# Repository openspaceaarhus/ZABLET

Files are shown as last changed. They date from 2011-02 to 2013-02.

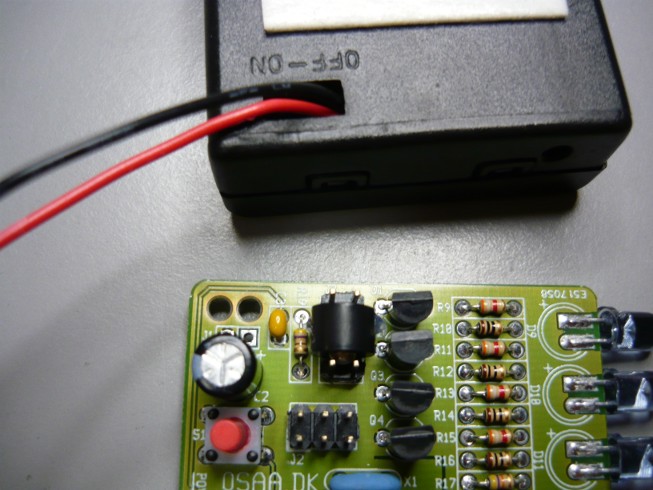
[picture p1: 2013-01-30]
doc/image/pwr-step01.jpg

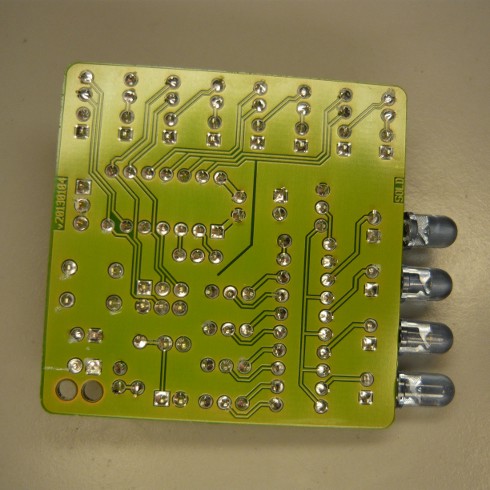
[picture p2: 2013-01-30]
doc/image/overview-pcb-sodlered-back.jpg

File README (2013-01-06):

Zab-Let
-------

Zap all TVs in your neighborhood.

This project is a derivative of the Adafruit TV-B-Gone project and includes a
POV too. The Zab-Let device was successfully used in a soldering workshop for
newbies. Version 2 fixes a few problems and extends the firmware to include the
POV part as a default.

See: http://zablet.osaa.dk
and our mailing list: http://groups.google.com/group/openspaceaarhus?hl=en

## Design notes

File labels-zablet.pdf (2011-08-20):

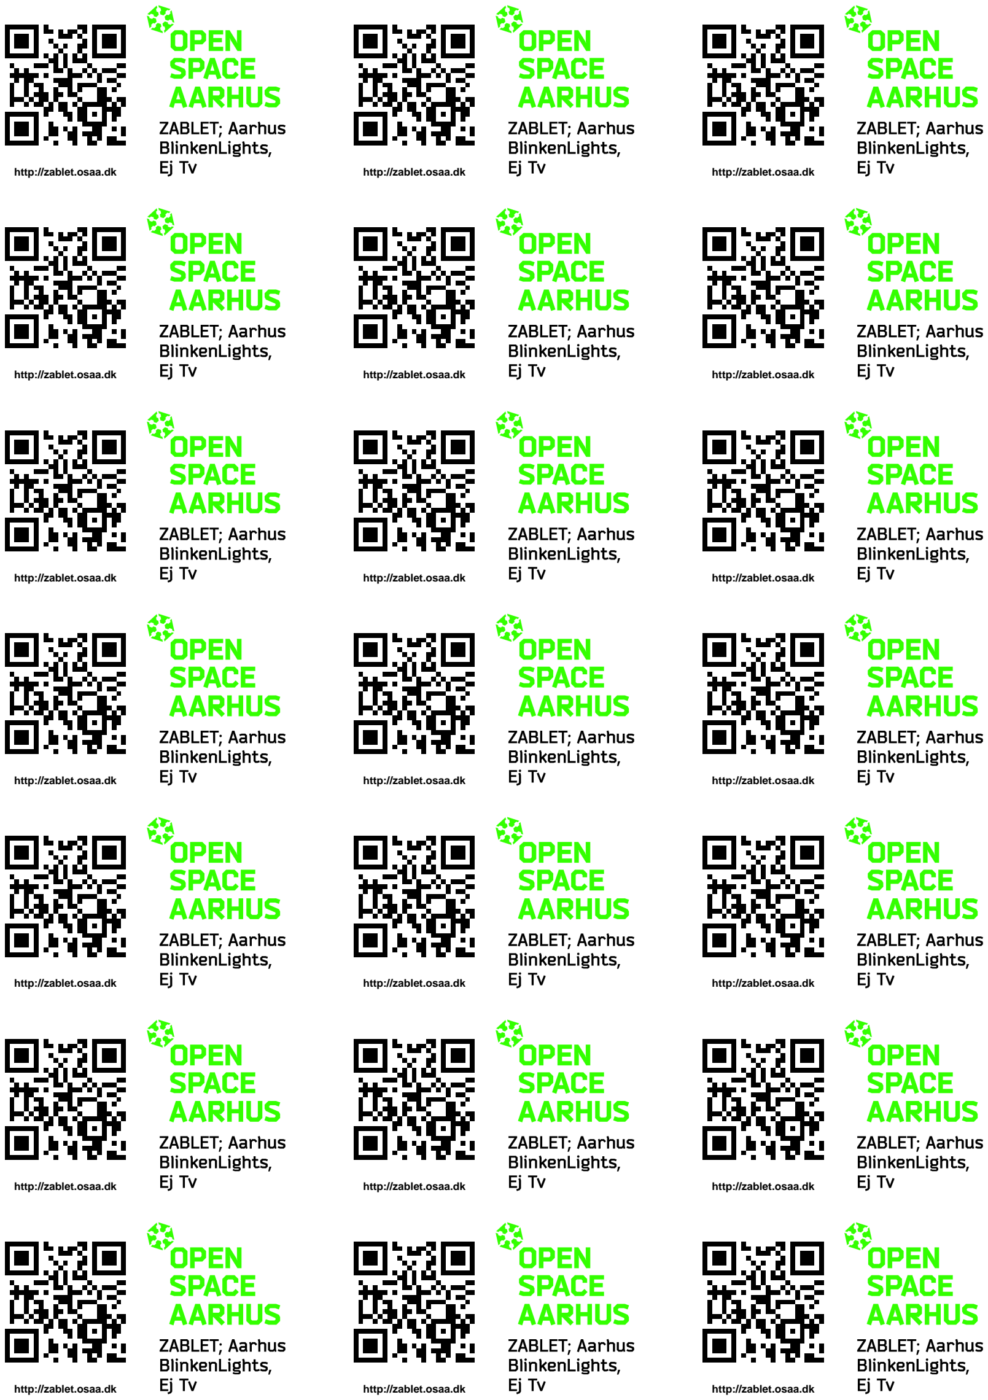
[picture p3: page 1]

http://zablet.osaa.dk | http://zablet.osaa.dk | http://zablet.osaa.dk
http://zablet.osaa.dk | http://zablet.osaa.dk | http://zablet.osaa.dk
http://zablet.osaa.dk | http://zablet.osaa.dk | http://zablet.osaa.dk
http://zablet.osaa.dk | http://zablet.osaa.dk | http://zablet.osaa.dk
http://zablet.osaa.dk | http://zablet.osaa.dk | http://zablet.osaa.dk
http://zablet.osaa.dk | http://zablet.osaa.dk | http://zablet.osaa.dk
http://zablet.osaa.dk | http://zablet.osaa.dk | http://zablet.osaa.dk

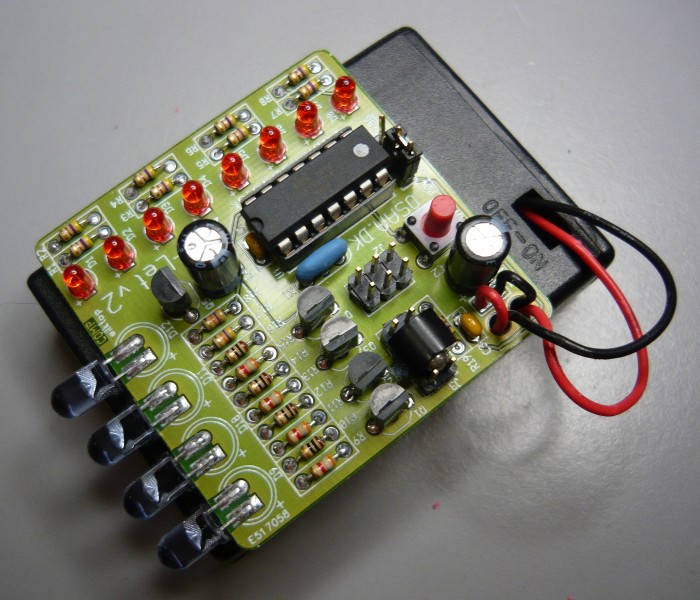
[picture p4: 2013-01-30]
doc/image/overview-finished.jpg

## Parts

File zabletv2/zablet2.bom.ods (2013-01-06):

qty | refdes | device | value | footprint | Mouser-ID | 1 | 10 | 100 | 1000 | 1 | 10 | 100 | 1000 | Elfa-ID | 1 | 10 | 100 | 1000
2 | C1,C3 | CAPACITOR | 100n | c100 | 75-1C10Z5U104M050B | 0.619 | 0.619 | 0.418 | 0.373 | 1.238 | 1.238 | 0.836 | 0.746 | 65-716-73 | 0.750 | 0.750 | 0.750 | 0.750
2 | C2,C4 | POLARIZED_CAPACITOR | 100u | cap_5x11_2.5 | 667-EEU-FR1C101 | 0.552 | 0.552 | 0.492 | 0.380 | 1.104 | 1.104 | 0.984 | 0.760 | 67-042-63 | 1.200 | 1.200 | 1.200 | 1.200
8 | D1,D2,D3,D4,D5,D6,D7,D8 | LED | Red | LED3 | 638-125410SURTS530A3 | 0.709 | 0.642 | 0.380 | 0.254 | 5.672 | 5.136 | 3.040 | 2.032 | 75-006-06 | 0.450 | 0.450 | 0.450 | 0.450
2 | D10,D12 | LED | IR333/H0 | LED5 | 638-IR333/H0/L10 | 2.250 | 2.250 | 1.540 | 0.836 | 4.500 | 4.500 | 3.080 | 1.672 | 75-225-43 | 0.830 | 0.830 | 0.830 | 0.830
2 | D11,D9 | LED | IR333-A | LED5 | 638-IR333-A | 1.480 | 1.480 | 0.985 | 0.507 | 2.960 | 2.960 | 1.970 | 1.014 | 75-203-75 | 0.830 | 0.830 | 0.830 | 0.830
1 | J1 | CONNECTOR_2 | unknown | JUMPER2 | - | 0.000 | 0.000 | 0.000 | 0.000 | 0.000 | 0.000 | 0.000 | 0.000 |  |  | 0.000 | 0.000 | 0.000
1 | J2 | CONNECTOR_6 | unknown | HEADER6_2 | . | 0.000 | 0.000 | 0.000 | 0.000 | 0.000 | 0.000 | 0.000 | 0.000 |  |  | 0.000 | 0.000 | 0.000
1 | J3 | CONNECTOR_8 | unknown | HEADER8_2 | . | 0.000 | 0.000 | 0.000 | 0.000 | 0.000 | 0.000 | 0.000 | 0.000 |  |  | 0.000 | 0.000 | 0.000
1 | JP1 | CONNECTOR_3 | unknown | JUMPER3 | 649-68024-103H | 0.679 | 0.679 | 0.545 | 0.433 | 0.679 | 0.679 | 0.545 | 0.433 | 43-716-13 | 1.200 | 1.200 | 1.200 | 1.200
4 | Q1,Q2,Q3,Q4 | NPN_TRANSISTOR | unknown | TO92_CBE_A | 512-BC33740BU | 0.380 | 0.313 | 0.216 | 0.142 | 1.520 | 1.252 | 0.864 | 0.568 | 71-014-58 | 0.341 | 0.341 | 0.341 | 0.341
1 | Q5 | PNP_TRANSISTOR | BC557B | TO92_CBE_A | 512-BC558BTA | 0.380 | 0.380 | 0.194 | 0.112 | 0.380 | 0.380 | 0.194 | 0.112 | 71-014-65 | 0.169 | 0.169 | 0.169 | 0.169
4 | R10,R12,R14,R16 | RESISTOR | 10R | r250 | 299-10-RC | 0.716 | 0.425 | 0.142 | 0.075 | 2.864 | 1.700 | 0.568 | 0.300 | 60-052-50 | 0.298 | 0.298 | 0.298 | 0.298
9 | R1,R19,R2,R3,R4,R5,R6,R7,R8 | RESISTOR | 470R | r250 | 299-470-RC | 0.716 | 0.425 | 0.142 | 0.075 | 6.444 | 3.825 | 1.278 | 0.675 | 60-054-58 | 0.340 | 0.340 | 0.340 | 0.340
4 | R11,R13,R15,R9 | RESISTOR | 3k9 | r250 | 299-3.9K-RC | 0.716 | 0.425 | 0.142 | 0.075 | 2.864 | 1.700 | 0.568 | 0.300 | 60-055-65 | 0.340 | 0.340 | 0.340 | 0.340
2 | R17,R18 | RESISTOR | 47k | r250 | 299-47K-RC | 0.716 | 0.425 | 0.142 | 0.075 | 1.432 | 0.850 | 0.284 | 0.150 | 60-056-98 | 0.340 | 0.340 | 0.340 | 0.340
1 | S1 | SWITCH_PUSHBUTTON_NO | unknown | TYCO_FSM | 612-TL1105BF250 | 0.865 | 0.798 | 0.552 | 0.463 | 0.865 | 0.798 | 0.552 | 0.463 | 35-665-52 | 1.870 | 1.870 | 1.870 | 1.870
1 | U1 | ATtiny84 DIP14 | unknown | DIP14 | 556-ATTINY84-20PU | 18.950 | 15.850 | 10.740 | 9.666 | 18.950 | 15.850 | 10.740 | 9.666 | 73-219-24 | 22.700 | 22.700 | 22.700 | 22.700
1 | X1 | CRYSTAL | 8MHz | resonator_BS_1 | 81-CSTLS8M00G56-B0 | 2.590 | 2.590 | 1.030 | 0.753 | 2.590 | 2.590 | 1.030 | 0.753 | 74-702-06 | 2.770 | 2.770 | 2.770 | 2.770
1 |  | Jumper |  |  | 806-SX1100-B | 0.194 | 0.194 | 0.134 | 0.127 | 0.194 | 0.194 | 0.134 | 0.127 | 43-711-10 | 0.600 | 0.600 | 0.600 | 0.600
1 |  | Socket | DIP14 |  | 649-DILB14P-223TLF | 0.739 | 0.739 | 0.670 | 0.530 | 0.739 | 0.739 | 0.670 | 0.530 | 48-155-62 | 0.970 | 0.970 | 0.970 | 0.970
1 |  | Battery holder 3xAA | 2487 |  | 534-2487 | 8.210 | 8.210 | 7.530 | 6.360 | 8.210 | 8.210 | 7.530 | 6.360 | 69-521-13 | 11.200 | 11.200 | 11.200 | 11.200
1 |  | PCB |  |  | Eurocircuits | 349.500 | 63.750 | 16.500 | 8.640 | 349.500 | 63.750 | 16.500 | 8.640 |  | 349.500 | 63.750 | 16.500 | 8.640
0 |  | PCB |  |  | SeeedStudio/itead | 141.93 | 14.193 | 6.27 | 5.814 | 0.000 | 0.000 | 0.000 | 0.000 |  | 0.000 | 0.000 | 0.000 | 0.000
3 |  | Battery AA | AA |  | Harald-Nyborg 3032 | 1.480 | 1.480 | 1.187 | 1.187 | 4.440 | 4.440 | 3.560 | 3.560 |  | 1.480 | 1.480 | 1.187 | 1.187
1 |  | Kugle | 3mm |  | Cykeldillen.dk J108 | 80.000 | 8.000 | 0.800 | 0.640 | 80.000 | 8.000 | 0.800 | 0.640 |  | 80.000 | 8.000 | 0.800 | 0.640
1 |  | Antistatic bag | 3x4” |  | 809-49101 | 31.030 | 3.103 | 0.310 | 0.310 | 31.030 | 3.103 | 0.310 | 0.310 | 80-072-05 | 32.600 | 3.260 | 0.326 | 0.326
 |  |  |  |  |  |  |  |  |  | 528.175 | 132.998 | 56.037 | 39.811 |  | 510.778 | 123.688 | 66.011 | 57.991
 |  |  |  |  |  |  |  | Inc VAT | 25.0% | 660.22 | 166.25 | 70.05 | 49.76 |  | 638.47 | 154.61 | 82.51 | 72.49
 | $ vs kr | 5.7
 |  |  |  |  |  |  |  | Sale: | 2.3 | 1214.80 | 305.90 | 128.89 | 91.57 |  | 1174.79 | 284.48 | 151.82 | 133.38
 |  |  |  |  |  |  |  | (in dollars) |  | 213.12 | 53.67 | 22.61 | 16.06 |  | 206.10 | 49.91 | 26.64 | 23.40
 |  |  |  |  | 24

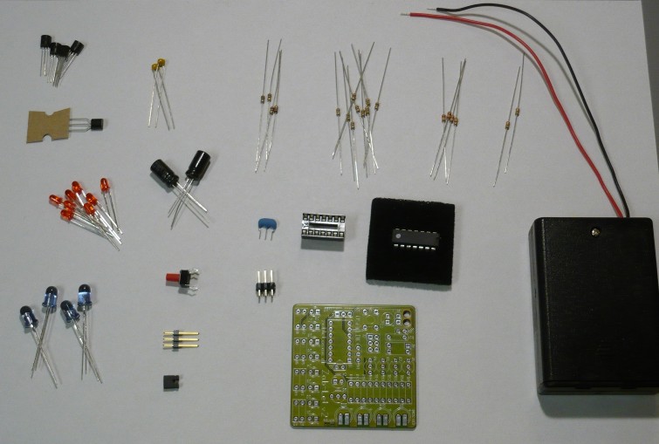
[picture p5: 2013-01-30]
doc/image/all-components.jpg

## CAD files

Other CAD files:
firmware/zabletv1/zablet.obj

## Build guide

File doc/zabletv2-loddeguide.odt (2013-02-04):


ZABLETv2 Loddeguide

(Zab-let Aarhus BlinkenLights Ej Tv 2)

# Introduktion

Tillykke med dit nye ZABLETv2 kit!

Idéen med ZABLETv2 kittet er at give dig øvelse i at lodde og indsigt i nogle praktiske elektroniske grundprincipper.

ZABLETv2'en er designet af foreningen Open Space Aarhus med stor inspiration fra Ladyadas TV-B-Gone og mini-POV. Den indeholder mere end 100 forskellige power koder til diverser TV mærker, og sender dem alle afsted på ca 16 sekunder efter aktivering. Ved POV (Persistence Of Vision) skrives en tekst i luften mens ZABLETv2'en rystes.

Designet er udført i open source programmet gplEDA, PCB'erne er produceret af Eurocircuits.

Dette dokument vil fortælle dig lidt om hvilke roller de enkelte komponenter i designet udfylder, for at ZABLETv2'en fungerer.

Hvis du har spørgsmål undervejs kan du altid spørge en af de venlige frivillige fra Open Space Aarhus. Vi står klar til at hjælpe!

# Loddeteori

Du skal bruge:

-en loddekolbe:

-en bidetang:

VARM! (310°C)

Tips:

- Start med de mindste (laveste) komponenter;
- Vær opmærksom på om din komponent kan vendes forkert! kig på silketrykket på PCB'en for at finde den rigtige orientering;
- Isæt komponenten, buk benene ud så den bliver siddende;
- Klip overskydende ben af så der er 2-3 mm tilbage;
- Tilfør varme;
- Tilfør tin;
- Fjern tin;
- Fjern varme;
- Hvis noget går galt kan man fjerne tinnet igen ved at bruge en tinsuger og/eller tinsugetråd. Spørg en af de frivillige om de ikke har noget liggende.. :)
- Hvis du har tvivl eller er usikker, spørg en af OSAA's frivillige for hjælp.

## Om lodderøg og loddetin

Loddetin er ikke sundt; men det er heller ikke farligt at have med at gøre hvis man enten bruger udsugning (som professionelle gør) eller kun arbejder med det nogle få timer om ugen.

Det kan dog anbefales at man vasker sine fingre inden man spiser for
at sikre mod indtagelse af snavs og farlige metaller og at man forsøger at ånde ud når det ryger mest.

# Diagram

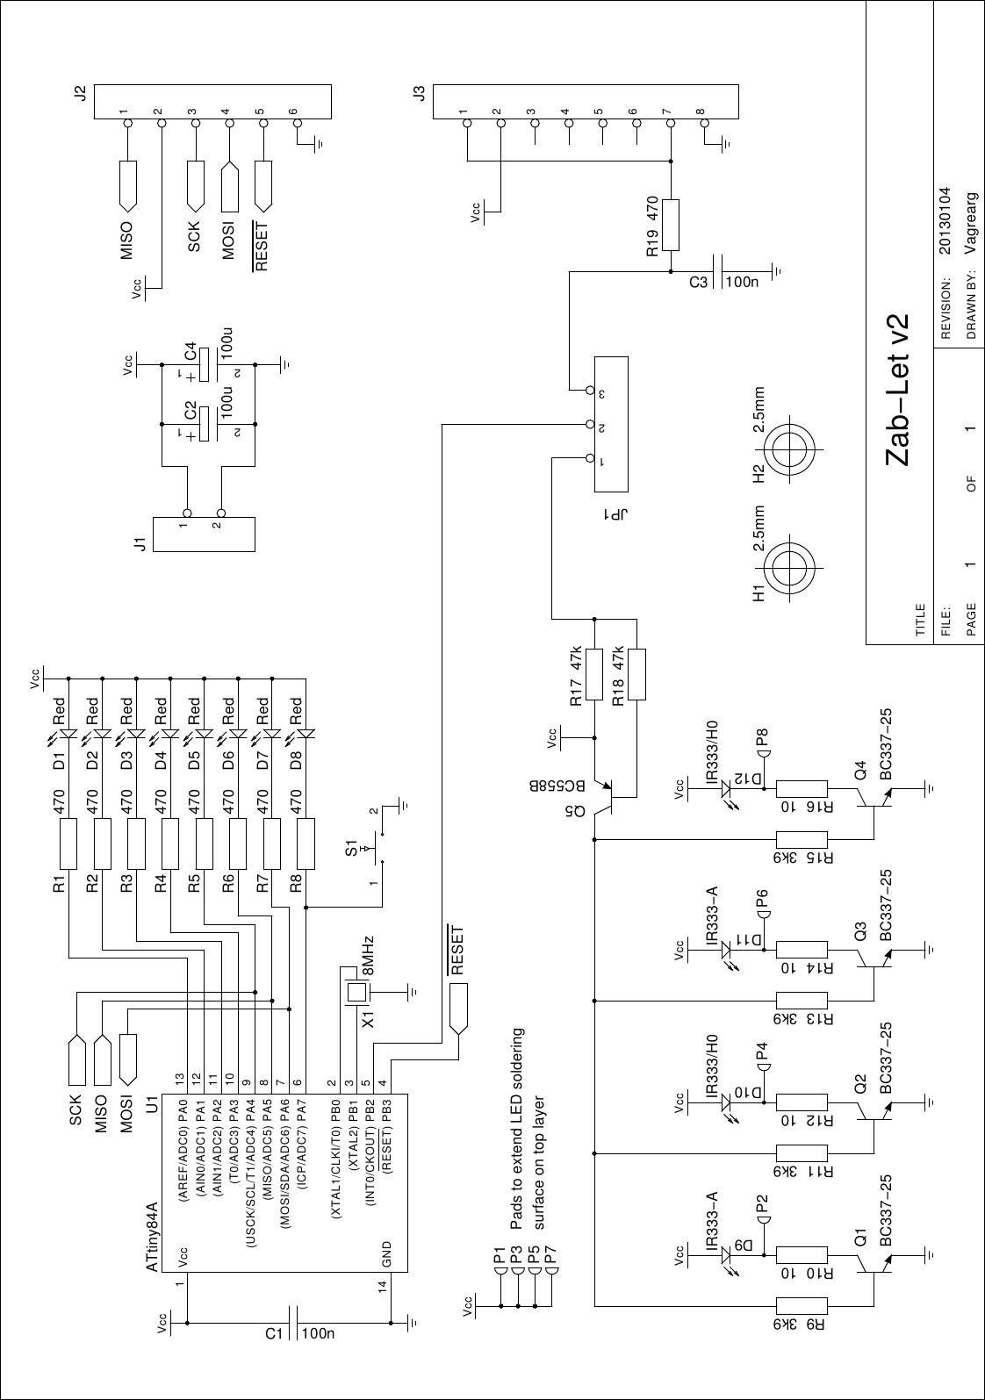
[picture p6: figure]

# Komponenter og montering

Alle komponenterne monteres på print-pladen på siden med silketryk.

Lodde-forbindelser laves på ”Lodde-siden”.

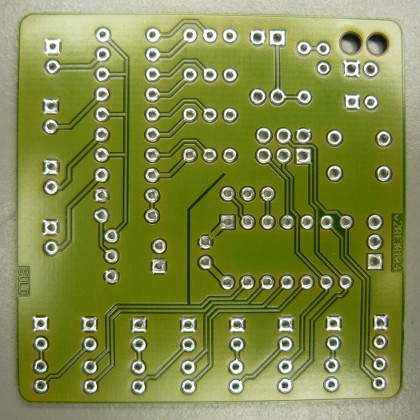
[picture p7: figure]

Lodde-siden

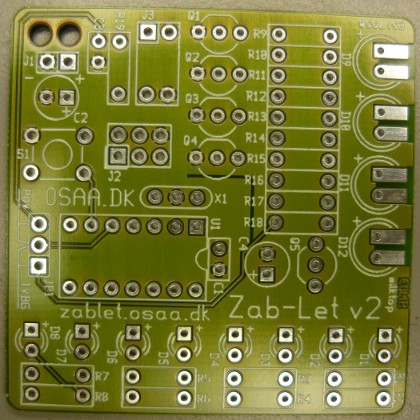
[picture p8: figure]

Komponent-siden

Der er ialt 46 komponenter der skal loddes på print-pladen. Derudover skal batteri-holderens ledningerne loddes og ”syes” igennem hullerne.

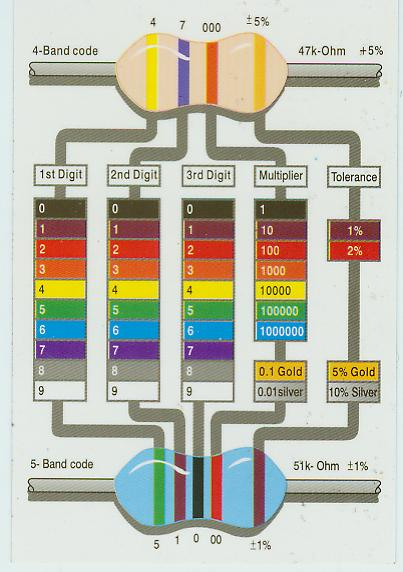
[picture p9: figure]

## Modstande

Modstande bruges til at begrænse strømmen mellem forbindelsespunkterne iflg. Ohms lov er strømmen (I) igennem modstanden betinget af spændingen (U) over modstanden og modstandens ohmske værdi (R) Det gælder at:

U=R*I => I=U/R => R=U/I

Modstande er farvekodede så man kan kende forskel på dem:

Modstande er ikke polariserede, dvs. Det er ligemeget hvilken vej de vender.

Europæisk (R1) og Amerikansk (R2) diagramsymbol for en modstand:

Zabletv2 kittet indeholder 19 modstande.

R1-R8, R19 (9 stk) - 470Ω

Farvekode: Gul, Lilla, Orange (guld)

Farvekode: Gul, Lilla, Brun (guld)

R1-R8 begrænser strømmen igennem LED'erne D1-D8. R19 sikrer mod en potentiel kortslutning og er del af POV-switch'ens filter.

R9, R11, R13, R15 (4 stk) – 3.9kΩ

Farvekode: Orange, Hvid, Rød (guld)

R9, 11, 13, 15 begrænser strømmen til transitorenes base Q1-Q4.

R10, R12, R14, R16 (4 stk) – 10Ω

Farvekode: Brun, Sort, Sort (guld)

R10, 12, 14, 16 begrænser strømmen til IR-LED'erne D1-D4 til omkring 200..250mA.

R17, R18 (2 stk) – 47kΩ

Farvekode: Gul, Lilla, Orange (guld)

R18 begrænser strømmen til PNP tansistorens base (Q5), og R17 fungerer som pull-up der holder transitoren slukket mens der ikke er et signal på basen.

## LED'er

LED står for Light Emitting Diode, det er som navnet antyder en lysdiode. Lyset kan være både synligt og infrarødt. I ZABLETv2'ens tilfælde bruges begge slags.

LED'er er ALTID polariserede!; det vil sige at de skal vende på en bestemt måde!

Diagramsymbol for en LED:

Anoden (+) kan findes på flere måder, 2 af måderne skal tages i brug ved montering på ZABLETv2'en:

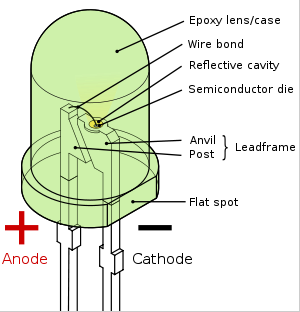
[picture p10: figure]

5mm IR-LED'er

3mm røde LED'er

ZABLETv2 kittet indeholder 12 LED'er; 4 stk 5mm IR-LED'er og 8 stk 3mm røde LED'er.

To typer IR-LED'er bruges. Den ene type har en større spredning for at opnå et bredt sendefelt og den anden type har lav spredning for at opnå større rækkevidde.

IR333-A | IR333/H0-L0

D9-D12 er Infrarøde LED'er

Det er meningen at IR-LED'erne skal pege fremad, dvs. at de skal ”lægges ned” før de loddes. Det er ligegyldigt hvordan de 4 IR-LED'er fordeles på de 4 pladser.

D1-D8 er ”almindelige” røde LED'er

I TV-B-Gone mode (jumper JP1 i TVBG positionen) fungerer de som en progress bar, der viser hvor langt ZABLETv2'en er kommet i afsendelsen af power koder.

I POV mode (jumper JP1 i POV positionen) sender de et lysbillede ud mens ZABLETv2'en bevæges frem og tilbage.

## Kondensatorer

Kondensatorer bruges til at udjævne støj og uregelmæssige spændinger. Anden anvendelse findes i filter funktionalitet. Kondensatorenes kapacitans måles i Farad (F). De er også markeret med en maksimal spænding.

Kondensatorer KAN VÆRE POLARISEREDE!

Diagram symboler: ikke polariseret C1, og polariseret C2 (Amerikansk), C3 (Europæisk):

Zablet kittet indeholder 4 kondensatorer.

C2, C4 – 100µF (25V) ER POLARISERET!

Elektrolytisk kondensator; minus er indikeret på huset med en hvid linie og '-' tegn

C2 og C4 er elektrolyt kondensatorer. Elektrolytter (eller ”lytter”) er polariserede. Det korte ben er minus, og det lange ben er plus.

Begge kondensatorer udjævner forsyningsspændingen, og aflaster batterierne ved at udglatte belastningen.

C1, C3 – 100nF (50V) er ikke polariseret

Keramisk kondensator

C1 og C3 er keramiske kondensatorer. Keramiske kondensatorer er som regel ikke polariserede.

C1 bruges som afkoblings-kondensator (udjævner støj), mens C3 har en filter-funktion til at holde på POV-switch'ens spænding.

## Transistorer

Transistorer kan bruges til meget, rigtig meget. De fungerer som strøm-forstærkere, hvor strømmen fra basen til emitteren forstærkes op og sendes ud mellem collectoren og emitteren. Allemindelige transistorer kendetegnes som BJT (Bipolar Junction Transistor), og findes i polaritet NPN og PNP.

En anden sjov implementering er at bruge transistoren som switch, hvor en lille strøm på basen kan tænde for en høj strøm fra collectoren til emitteren. Dybere transistor teori er der ikke plads til i denne loddeguide.

I denne opsætning bruges transitorene som switches til at tænde/slukke for IR-LED'erne

Der er 2 typer BJT transistorer i designet. Vær opmærksom på om teksten på transistorens hus identificerer den som BC337 eller BC558.

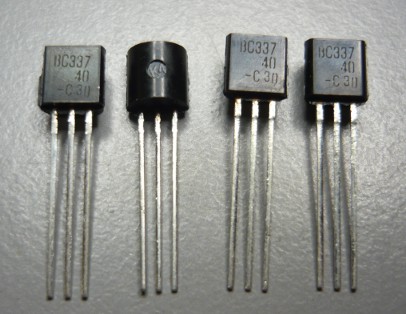
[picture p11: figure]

Q1-Q4 - NPN BJT – BC337

4 stk NPN transistorer driver den store strøm til IR-LED'erne - en for hver IR-LED.

Q5 – PNP BJT – BC558

1 stk PNP transistor – Bruges til at tænde for de 4 andre transistorer.

## Trykknap

Trykknappen (S1) tænder for IR-LED'erne, og fjernbetjeningens sluk-koder sendes en for en. Hvis knappen holdes nede i 3 sekunder afbrydes processen, og ZABLETv2'en går tilbage i sove-mode.

## Jumper

En jumper er en switch der kan stilles i en eller flere retninger. Jumperen vælger om ZABLETv2'en kører POV eller TV-B-Gone. Pin-headeren loddes på printet på position JP1.

## Sokkel

En sokkel er til nemt at indsætte eller fjerne chips. Der er 14 ben i denne sokkel, og der er en markering til orientering (indhak på venstre side). Markeringen bruges til at identificere pin 1, som er venstre nederst på billedet. Silketrykket på printet har samme markering (U1).

## Resonator

En resonator giver meget præcist takt til microcontrolleren. Resonatoren der bruges (X1) giver 8000000 svingninger i sekundet (8MHz).

## µController

µControlleren (Microcontrolleren , eller µC'en) er af typen ATTiny84 (U1). Den indeholder den kode der er skrevet og kompileret til den af Open Space Aarhus' ZABLET gruppe.

Det fede ved denne type chip er at den kan omprogrammeres mens den sidder i kredsen (via J2), så du har faktisk samlet dig et lillebitte såkaldt development board.

Find en OSAA frivillig når du mener du er klar til at teste din ZABLET, så finder vi en µController frem til dig, og hjælper med at montere den.

Det er vigtigt at µControlleren vender rigtigt, find markeringen på den ene ende a chippen og isæt den så den passer med markeringen på soklen (som passer med markeringen på printet).

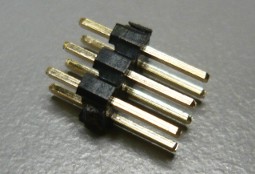
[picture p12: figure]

## Programming pin header

Programmering af microcontrolleren foregår ved at tilslutte en programmer på headeren (J2). De 6 ben på pin-headeren indeholder alle signaler der skal til programmering.

Find en OSAA frivillig når du har lyst til at lave om på programmeringen, og ændre POV teksten der vises i luften.

## POV-switch

Persitence Of Vision (POV) kræver en afbryder der giver kontakt når ZABLETv2'en bevæges frem og tilbage. Afbryderen er lavet af en 8-pin header hvor nogle pins er fjernet, og erstattet med en kugle i et rør. POV-switch'en fremstilles som følgende:

| | POV-switch elementer

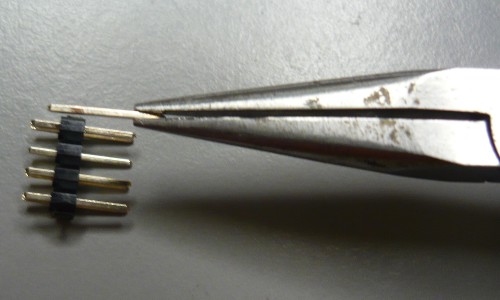
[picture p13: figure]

| | Fjern de midterste fire pins ved at trække dem ud af plastikken;
| | Når pins'ene er fjernet er der fire tilbage i hjørnerne;

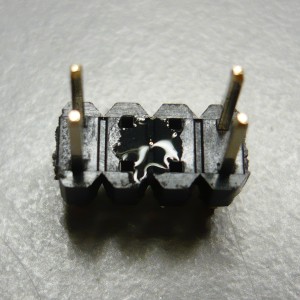
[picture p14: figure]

| | Placer en meget lille dråbe sekundlim (cyanoacrylate) på midten;

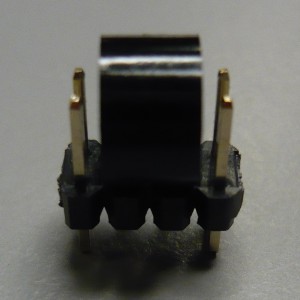
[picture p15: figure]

| | Placer røret med kuglen i røret på pin-headeren, og sørg for at røret er centreret i alle retninger, og ikke roteret;

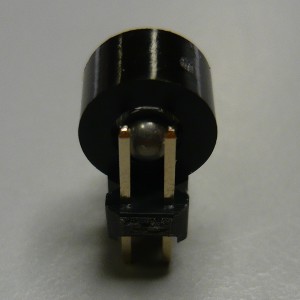
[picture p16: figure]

| | Center position af røret er vigtigt for at kuglen kan lave god kontakt med pins'ene på begge sider af røret;
| | Efter sekundlim er tørret, tag varmelim-pistolen, og fikser røret til headeren på begge sider;
| | Når limen er størknet, kan du lodde POV-switch'en i din ZABLETv2.

## Resultat

Når alle komponenter er loddet ser det nogenlunde sådan ud:

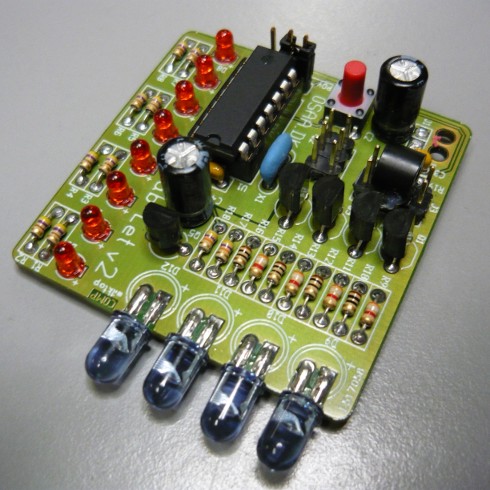
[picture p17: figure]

# De sidste stumper

Når print-pladen er færdiglavet, skal du have tilsluttet batterierne. Vi har lavet nogle små modifikationer til batteri-holderen for at gøre det pænere, og at ledningerne ikke forstyrer for meget.

## Batterypackhack

For at ledningerne nemmere når til print-pladen, og ikke forstyrer, skal ledningerne flyttes fra side-hullet til top-hullet i batteri-holderen.

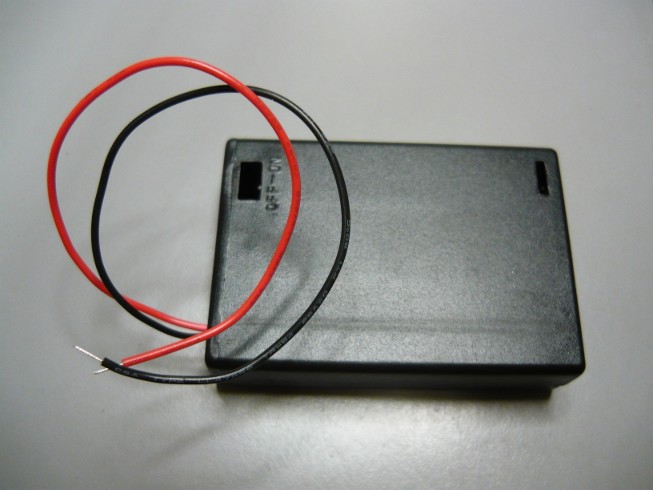
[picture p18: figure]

Umodificeret batteri-holder set fra oven | Umodificeret batteri-holder set fra bunden
| Åben batteri-holderen ved at fjerne skruen og lågen;

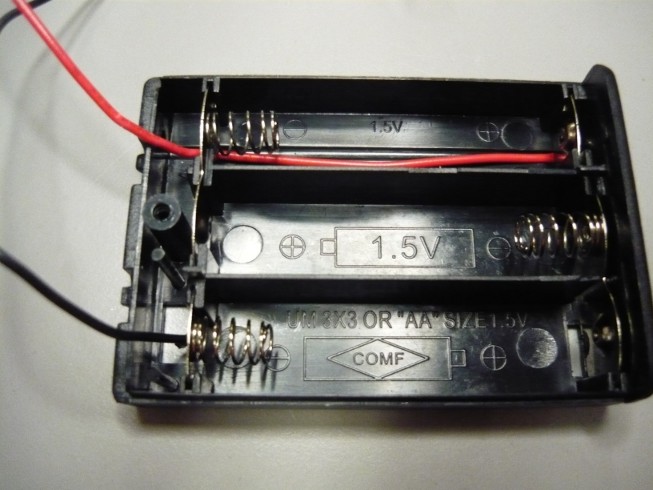
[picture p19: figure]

| Tryk/træk ledningerne forsigtigt tilbage igennem hullet;
| Læg ledningerne i en løkke og før dem igennem åbningen i toppen;

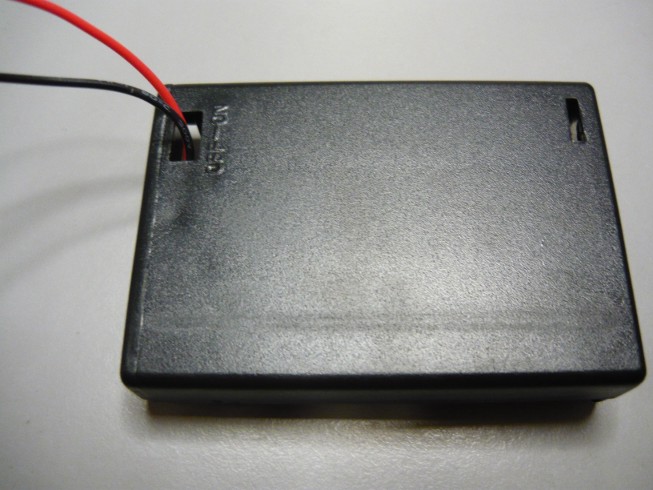
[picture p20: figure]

| Batterypackhack er gennemført, og holderen kan lukkes igen med skruen.

## Batteri forbindelsen

Som afslutning skal du forbinde batteri-holderen til din ZABLETv2. Der er lavet to huller i print-pladen til aflastning af lodningerne. Den røde og sorte ledning fra batteri-holderen skal gennemføres hullerne på en speciel måde som beskrevet her:


| Når du er færdig med at lodde din ZABLETv2, og har lavet batterypackhack, så skal de to forbindes.
| Før begge ledninger igennem et hul fra komponent-siden. Den røde ledning skal igennem hjørne-hullet;
| Tryk ledningerne tilbage igennem det modsatte hul, således at ledningerne ”syes” igennem hullerne;

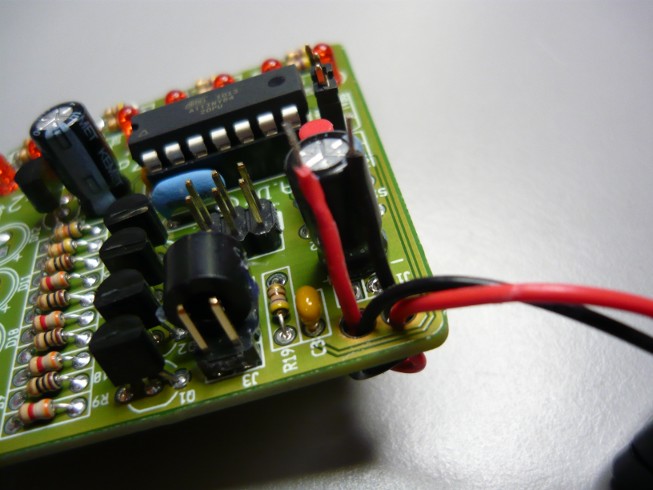
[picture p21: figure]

| Træk begge ender op igennem hullerne, således at de stikker omkring 1,5cm op;
| Træk begge ledninger tilbage fra batteri-holderen for at stramme dem på bund-siden;
| Du har lavet en træk-aflastning på begge ledninger;

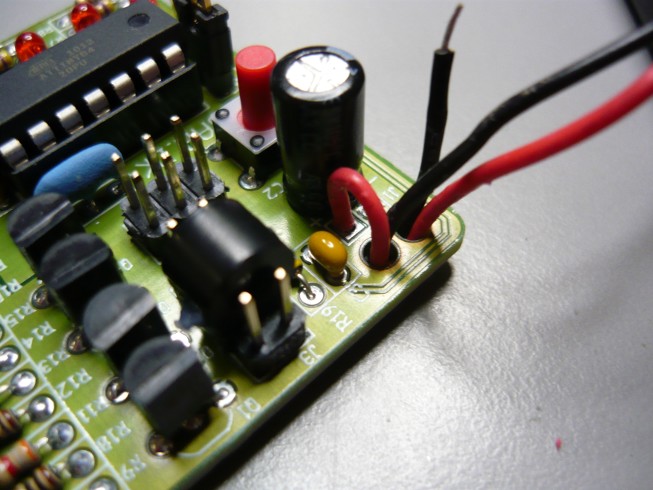
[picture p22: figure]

| Bøj den røde ledning (plus-pol) og put den i hullet tilhørende J1 ved markering + (det er den firkantede lodde-pad);
| Lod plus-forbindelsen;

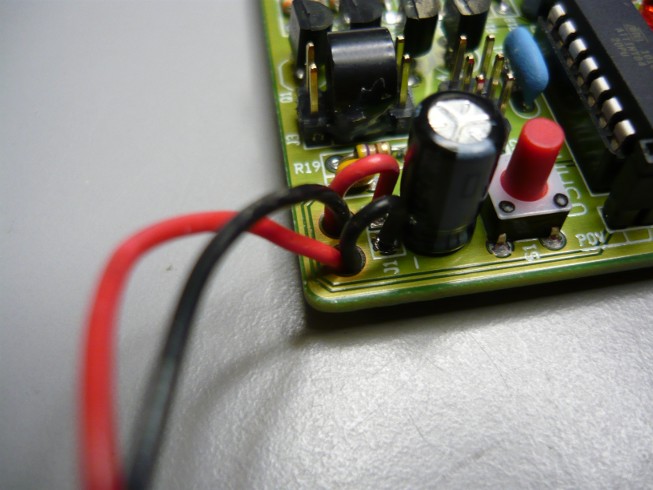
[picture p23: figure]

| Bøj den sorte ledning (minus-pol) og put den i hullet tilhørende J1 ved markering -;

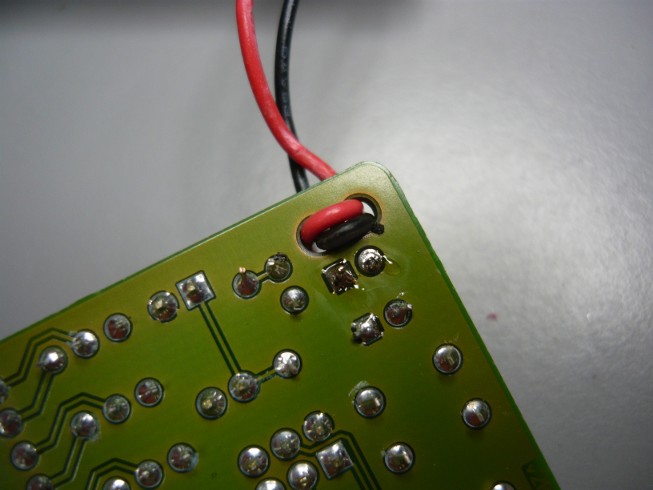
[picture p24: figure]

| Lod minus-forbindelsen, og færdig.

Når du er færdig, kan du fiksere print-pladen på batteri-holderen med tape, og gå over til test.

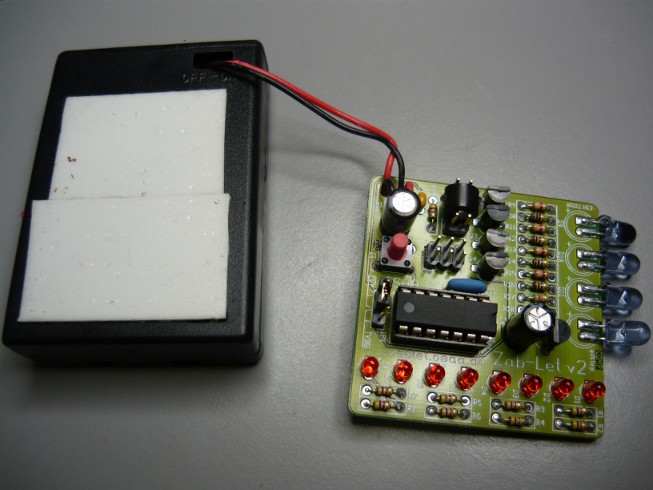
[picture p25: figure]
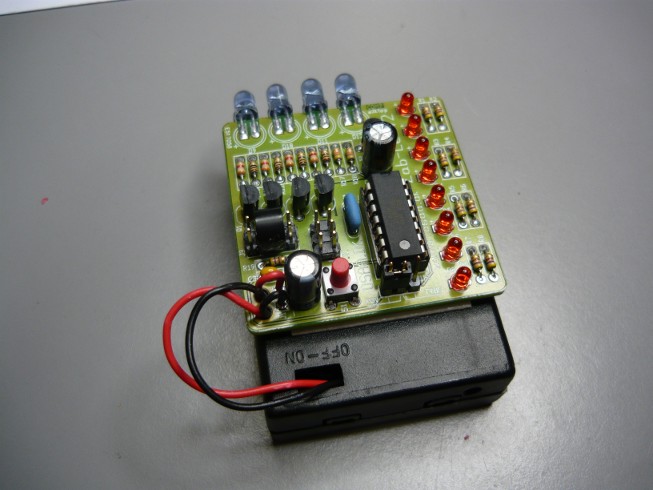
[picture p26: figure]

# Test

For at teste TV-B-Gone funktionaliteten af din nye ZABLETv2 skal jumperen JP1 stå i TVBG positionen. Nu kan du med et hvilket som helst digital-kamera verificere at IR-LED'erne blinker under afvikling af sluk-koderne. Tjek også at alle de røde LED'er lyser op undervejs, i takt med at ZABLETv2'en kommer igennem alle koderne.

For at teste POV funktionaliteten af ZABLETv2'en skal jumperen JP1 stå i POV positionen. Nu skulle du kunne skrive i luften med lyset fra de røde LED'er ved at vifte ZABLETv2'en frem og tilbage. Hold godt fast! Kan du læse hvad der står?

# Omprogrammering?

Kunne du selv tænke dig at rode med koden, og se om du kan få ZABLETv2'en til at opføre sig anderledes, eller vil du bare have ZABLETv2'ens POV til at skrive noget andet?

Al den kode der skal til for at programmere, og omprogrammere ZABLETv2'en findes på github, og findes nemt via http://zablet.osaa.dk.

Spørg gerne en af de tilstedeværende OSAAianere om de vil hjælpe dig med at ændre på softwaren så den opfylder netop dine behov.

# Komponent-liste

Antal | Reference | Værdi | Type
4 | R10, R12, R14, R16 | 10Ω | Modstand
9 | R1, R2, R3, R4, R5, R6, R7, R8, R19 | 470Ω | Modstand
4 | R9, R11, R13, R15 | 3.9kΩ | Modstand
2 | R17, R18 | 47kΩ | Modstand
2 | C1, C3 | 0.1µF | Kondensator
2 | C2, C4 | 100µF | Elektrolyt
8 | D1, D2, D3, D4, D5, D6, D7, D8 | 1254-10SURT | 3mm rød LED
2 | D9, D11 | IR333-A | 5mm IR-LED
2 | D10, D12 | IR333/H0-L0 | 5mm IR-LED
4 | Q1, Q2, Q3, Q4 | BC337-25[^1] | NPN BJT
1 | Q5 | BC558B[^2] | PNP BJT
1 | X1 | 8MHz | Resonator
1 | U1 | ATTiny84 | µController
1 | S1 | TL1105BF250 | Trykknap
1 | JP1 | 3x1-pin header
1 | J2 | 3x2-pin header
1 | J3 | 4x2 pin-header | Se afsnit 4.11
1 | - | 5mm afstands-stykke | Se afsnit 4.11
1 | - | 3mm stålkugle | Se afsnit 4.11
1 | - | jumper
1 | (U1) | sokkel DIP14
1 | - | batteri-holder (2487)
1 | - | PCB 50x50mm

[^1] Kan erstattes med BC337-40
[^2] Kan erstattes med BC557B eller BC559B

Open Space Aarhus' ZABLETv2 loddeguide

Open Space Aarhus – OSAA.dk - 24/24

Open Space Aarhus’ ZABLET loddeguide – Loddeteori

Open Space Aarhus – OSAA.dk

Open Space Aarhus’ ZABLET loddeguide – Komponenter og montering

Open Space Aarhus’ ZABLET loddeguide – Test / Omprogrammering

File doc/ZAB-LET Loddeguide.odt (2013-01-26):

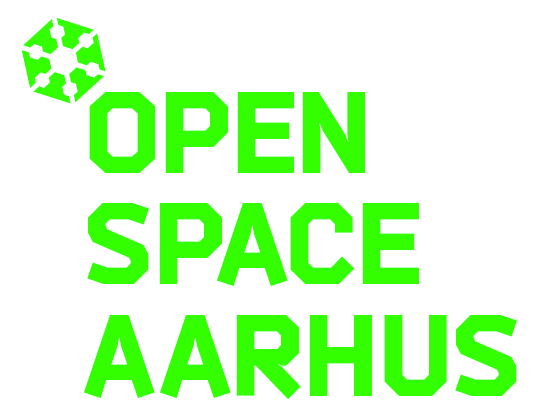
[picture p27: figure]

ZABLET Loddeguide

(Zab-let Aarhus BlinkenLights Ej Tv)

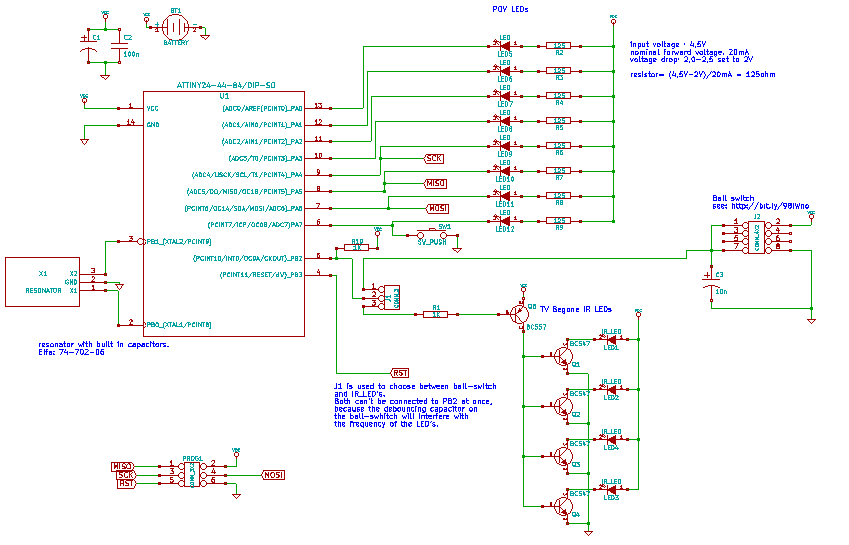
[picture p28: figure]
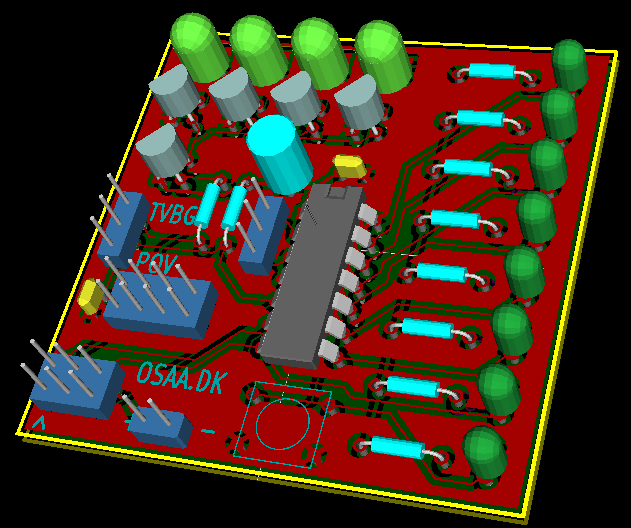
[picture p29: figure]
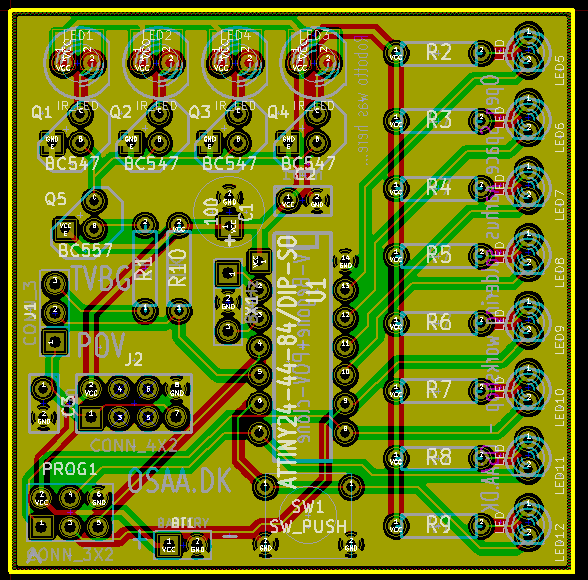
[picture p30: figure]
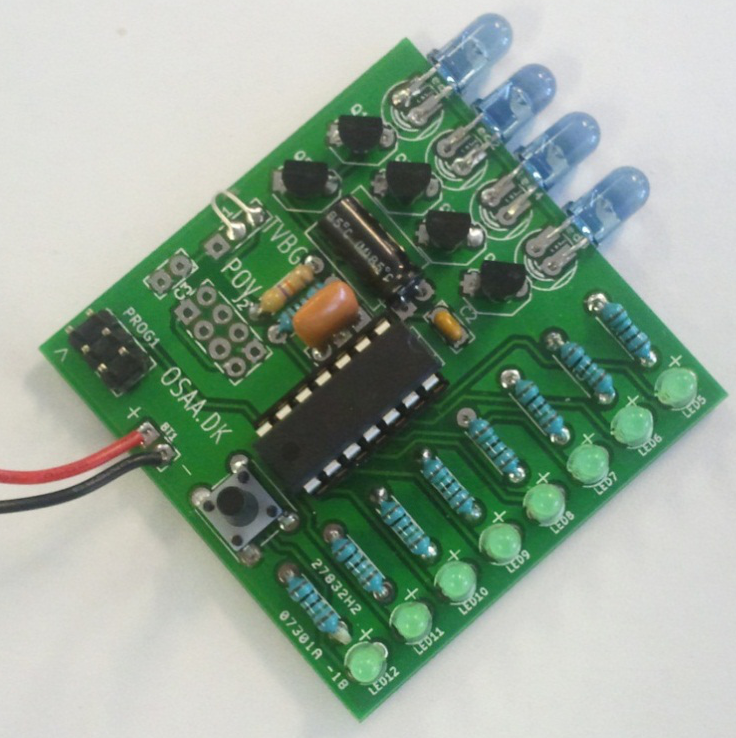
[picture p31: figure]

# Indhold

# Introduktion

Tillykke med dit nye ZABLET kit!

Idéen med ZABLET kittet er at give dig øvelse i at lodde og indsigt i nogle praktiske elektroniske grundprincipper.

ZABLET’en er designet af foreningen Open Space Aarhus med stor inspiration fra Ladyadas TV-B-Gone. Den indeholder mere end 100 forskellige power koder til diverser TV mærker, og sender dem alle afsted på ca 16 sekunder efter aktivering.

Designet er udført i open source programmet KiCAD, PCB’erne er produceret af ITEAD studio.

Dette dokument vil fortælle dig lidt om hvilke roller de enkelte komponenter i designet udfylder, for at ZABLET’en fungerer.

Hvis du har spørgsmål undervejs kan du altid spørge en af de venlige frivillige fra Open Space Aarhus . Vi står klar til at hjælpe!

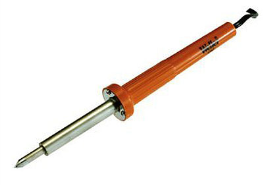
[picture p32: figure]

# Loddeteori

Du skal bruge: -en loddekolbe:

-en bidetang:

VARM! (375°C)

Tips :

- Start med de mindste komponenter

_ vær opmærksom på om din komponent kan vendes forkert!

kig på silketrykket på PCB’en for at finde

- Isæt komponenten, buk benene ud så den bliver siddende.

- Klip overskydende ben af så der er 2-3 mm tilbage

- Tilfør varme

- Tilfør tin

- Fjern tin

- Fjern varme

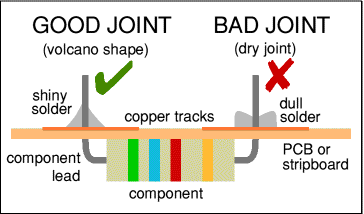
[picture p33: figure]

- Hvis noget går galt kan man fjerne tinnet igen ved at bruge en tinsuger og/eller tinsugetråd. Spørg en af de frivillge om de ikke har noget liggende.. :)

Om lodderøg og loddetin

Loddetin er ikke sundt.. Men det er heller ikke farligt at have med at gøre hvis man enten bruger udsugning (som professionelle gør) eller kun arbejder med det nogle få timer om ugen.
Det kan dog anbefales at man vasker sine fingre inden man spiser for
at sikre mod indtagelse af bly og at man forsøger at ånde ud når det
ryger mest.

# Diagram

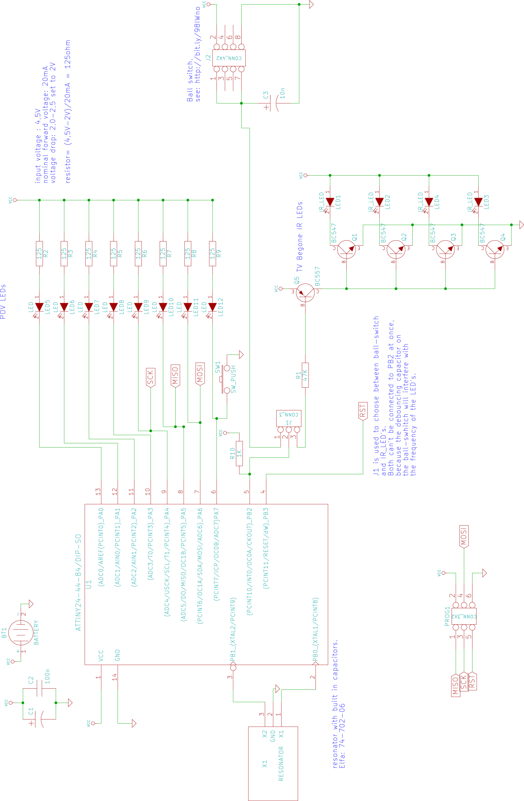
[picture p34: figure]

# Komponenter og montering

## - Modstande

Modstande bruges til at begrænse strømmen mellem forbindelsespunkterne iflg. Ohms lov er strømmen (I) igennem modstanden betinget af spændingen (U) over modstanden og modstandens ohmske værdi (R) Det gælder at:

U=R*I => I=U/R => R=U/I

Modstande er farvekodede så man kan kende forskel på dem:

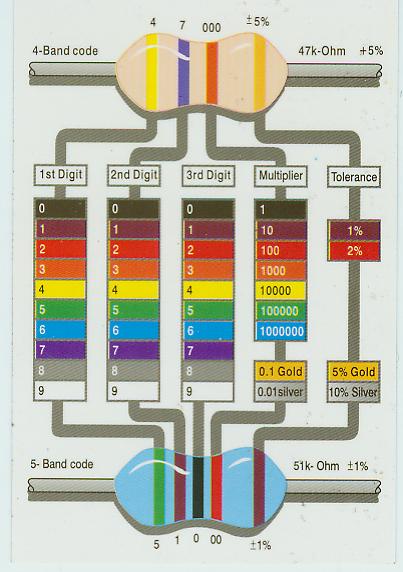
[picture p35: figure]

Modstande er ikke polariserede, dvs. Det er ligemeget hvilken vej de vender.

Europæisk (R1) og Amerikansk (R2) diagramsymbol for en modstand:

Zablet kittet indeholder 10 modstande

R1 – 47KΩ

Farvekode: Gul, Lilla, Orange (og guld = 5% tolerance)

R1 begrænser strømmen til PNP tansistorens base (Q5)

R2-R9 (8 stk) - 150Ω (er tæt nok på 125 Ω)

Farvekode: Brun, Grøn, Brun (og guld = 5% tolerance)

R2-R9 begrænser strømmen igennem LED’erne LED5-LED12

R10 – 1KΩ

Farvekode: Brun, Sort, Rød (og guld = 5%)

R10 er en pull-up modstand der sørger for at en pin på µControlleren ikke ”svæver” (PORTB2 forbindes til 4,5V mens modstanden tillader en minimal strøm)

## - LED’er

LED står for Light Emitting Diode, det er som navnet antyder en lysdiode. Lyset kan være både synligt og infrarødt. I ZABLET’ens tilfælde bruges begge slags.

LED’er er ALTID polariserede!

Det vil sige at de skal vende på en bestemt måde!

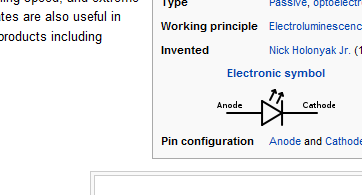
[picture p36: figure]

Diagramsymbol for en LED:

Anoden, (+) kan findes på flere måder, 2 af måderne skal tages i brug ved montering på ZABLET’en:

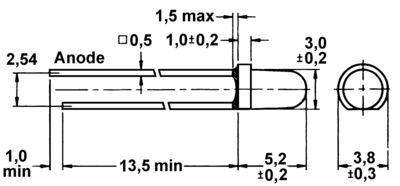
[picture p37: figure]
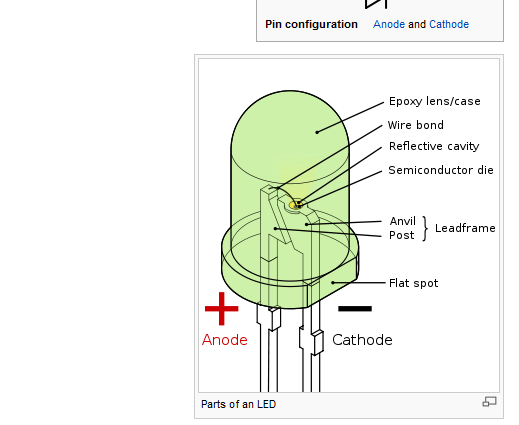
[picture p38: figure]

Zablet kittet indeholder 12 LED’er:

4stk 5mm IR-LED’er og 8 stk 3mm grønne LED’er

LED1 – LED4 er Infrarøde LED’er

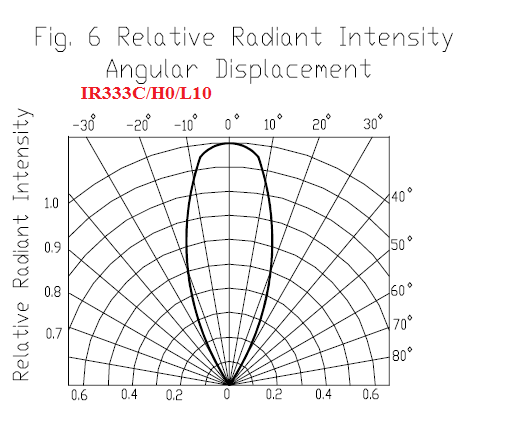
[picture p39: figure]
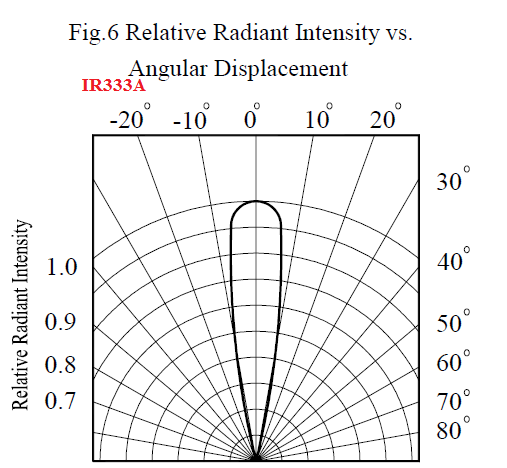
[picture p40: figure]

To af dem har større spredning for at opnå et bredt sendefelt og to af dem har lav spredning for at opnå større rækkevidde:

Det er meningen at IR-LED’erne skal pege fremad, dvs. at de skal ”lægges ned” før de loddes. Det er ligegyldigt hvordan de 4 IR-LED’er fordeles på de 4 pladser.

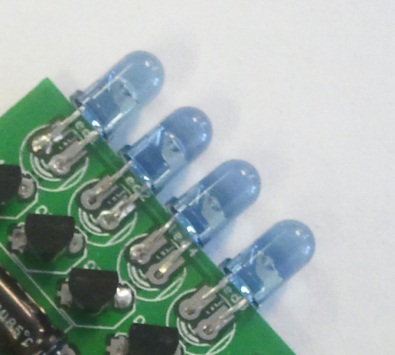
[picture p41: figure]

LED5 - LED12 er ”almindelige” grønne LED’er

I øjeblikket fungerer de som en progress bar, der viser hvor langt ZABLET’en er kommet i afsendelsen af power koder.

## – Kondensatorer

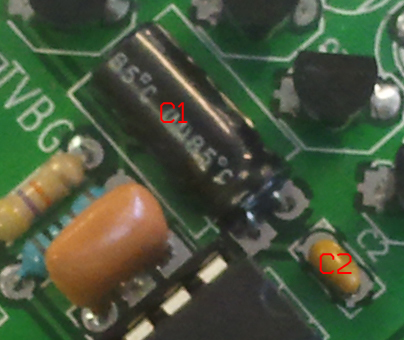
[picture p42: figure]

Kondensatorer bruges (i dette tilfælde) til at udjævne støj og uregelmæssige spændinger. Deres kapacitans måles i Farad (F). De er også markeret med en maksimal spænding.

Kondensatorer KAN VÆRE POLARISEREDE!

Zablet kittet indeholder 2 kondensatorer.

Diagram symbol: polariseret (C1) og ikke polariseret (C2):

C1 – 100µF (16V) ER POLARISERET!

C1 er en elektrolyt kondensator.

Elektrolytter (eller ”lytter”) er som regel polariserede.

+

C1 skal ”lægges ned” på printet.

C2 – 10nF (50V) er ikke polariseret

C2 er en keramisk kondensator.

Keramiske kondensatorer er som regel ikke polariserede.

( C3 er ikke implementeret i nuværende konfiguration. )

## – Transistorer

Transistorer kan bruges til meget.. rigtig meget.. de fungerer primært som strøm-forstærkere hvor strømmen på basen forstærkes op og sendes ud på emitteren.

En anden sjov implementering er at bruge transistoren som switch, hvor en spænding på basen kan tænde for en strøm fra collectoren til emitteren.

Dybere transistor teori er der ikke plads til i denne loddeguide...

(og her var diagram symbolet for en NPN BJT)

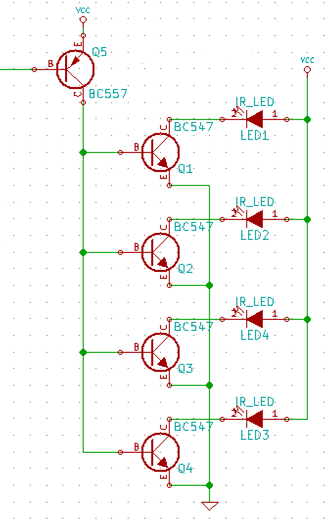
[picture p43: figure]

I denne opsætning bruges de som switches til at tænde/slukke for IR-LED’erne

Der er 2 typer BJT transistorer i designet:

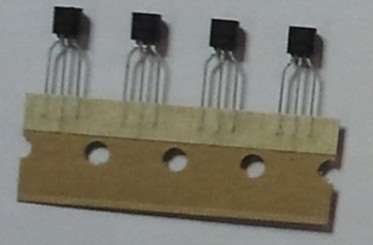
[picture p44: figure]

Q1-Q4 - NPN BJT – BC547

4 stk NPN transistorer - En for hver IR-LED.

Q5 – PNP BJT – BC557

1 stk PNP transistor – Bruges til at tænde for de 4 npn transistorer.

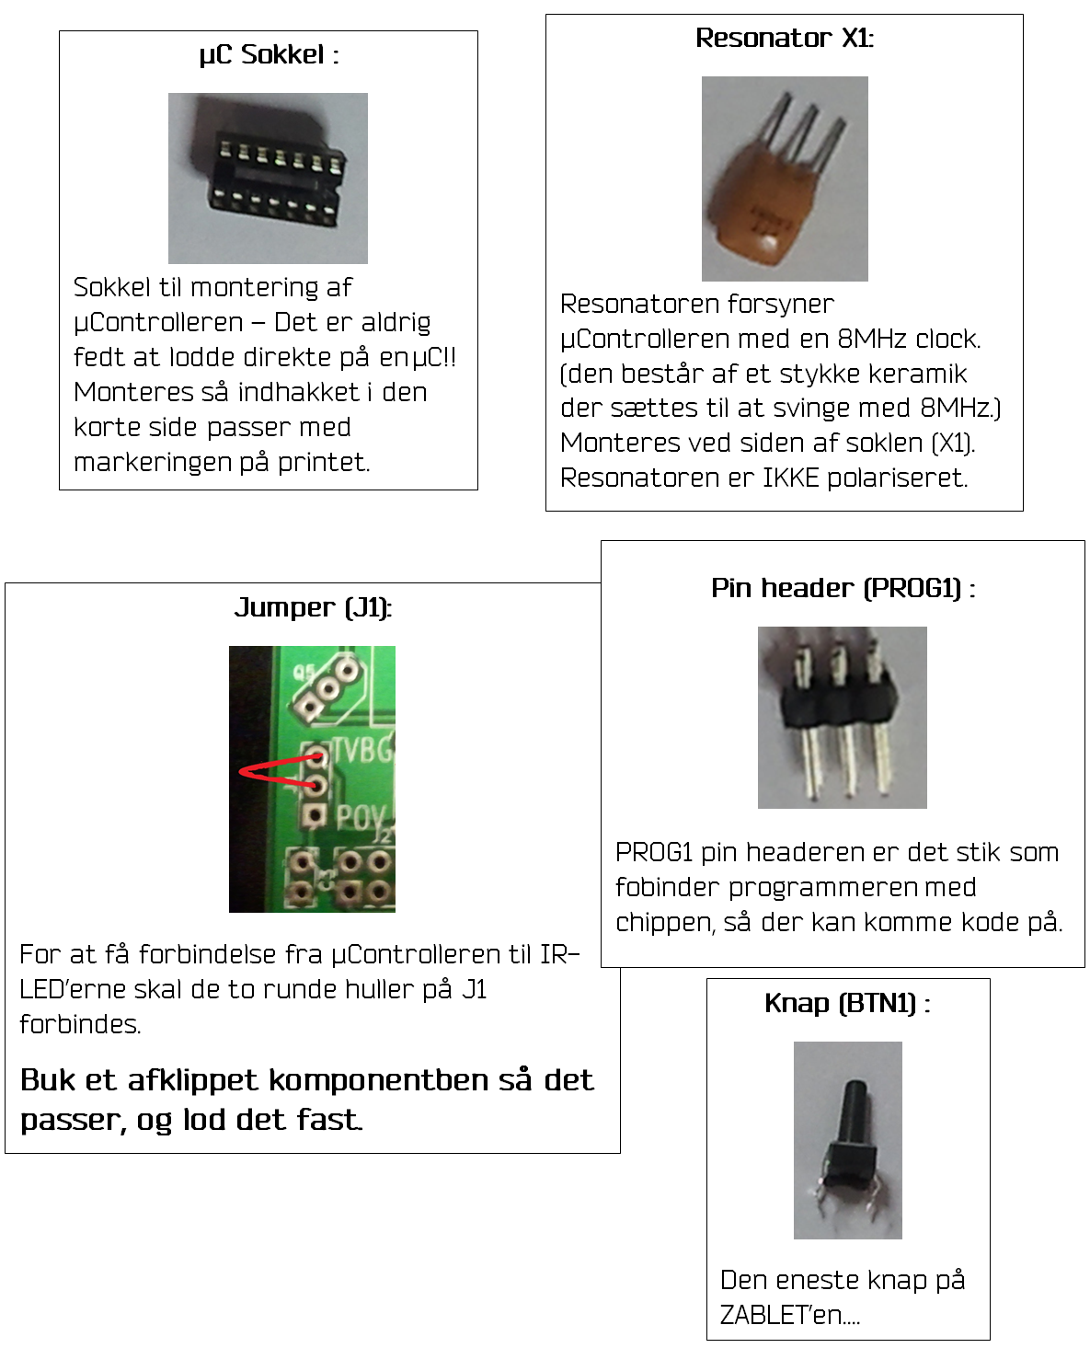
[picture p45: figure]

## - Sokkel, resonator, pin header, knap, jumper


## - µController

µControlleren (Microcontrolleren , eller µC’en) er af typen ATTiny84

Den indeholder den kode der er skrevet og kompileret til den af Open Space Aarhus’ ZABLET gruppe.

Det fede ved denne type chip er at den kan omprogrammeres mens den sidder i kredsen (Via PROG1), så du har faktisk samlet dig et lillebitte såkaldt development board.

Find en OSAA frivillig når du mener du er klar til at teste din ZABLET, så finder vi en µController frem til dig, og hjælper med at montere den.

Det er vigtigt at µControlleren vender rigtigt, find markeringen på den ene ende a chippen og isæt den så den passer med markeringen på soklen (som passer med markeringen på printet)

## - Batterypackhack

Batteripakken som følger med ZAB-LET’en har et hul i bunden hvor man kan føre ledningerne ud. Dette gør monteringen mere lækker, og er at foretrække frem for at ledningen stikker ud af bunden og går rundt:


# Test

Test funktionaliteten af din ZABLET ved at pege IR-LED’erne mod et hvilket som helst digitalkamera, og se om de lyser når du har trykket på knappen:


# Omprogrammering?

http://zablet.osaa.dk redirecter til et github repository hvor den nuværende kildekode kan hentes. De Fleste AVR ISP programmers skulle kunne snakke med ATTiny’en. Held og lykke! :)

## - Sokkel, resonator, pin header, knap, jumper

Resonator X1:

Resonatoren forsyner µControlleren med en 8MHz clock. (den består af et stykke keramik der sættes til at svinge med 8MHz.) Monteres ved siden af soklen (X1). Resonatoren er IKKE polariseret.

µC Sokkel :


Sokkel til montering af µControlleren – Det er aldrig fedt at lodde direkte på en IC!!

Monteres så indhakket i den korte side passer med markeringen på printet.

Pin header (PROG1) :

PROG1 pin headeren er det stik som fobinder programmeren med chippen, så der kan komme kode på.

Jumper (J1):

For at få forbindelse fra µControlleren til IR-LED’erne skal de to runde huller på J1 forbindes.

Buk et afklippet komponentben så det passer, og lod det fast.

Knap (BTN1) :

Den eneste knap på ZABLET’en....

Open Space Aarhus’ ZABLET loddeguide – Komponenter og montering

Open Space Aarhus – OSAA.dk

Open Space Aarhus’ ZABLET loddeguide – Loddeteori

Open Space Aarhus’ ZABLET loddeguide - Introduktion

Open Space Aarhus’ ZABLET loddeguide - Diagram

Open Space Aarhus’ ZABLET loddeguide – Test / Omprogrammering

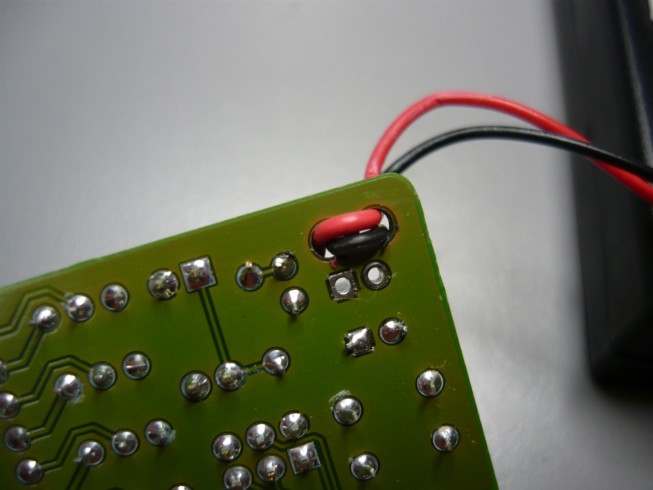
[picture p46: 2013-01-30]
doc/image/pwr-step05.jpg

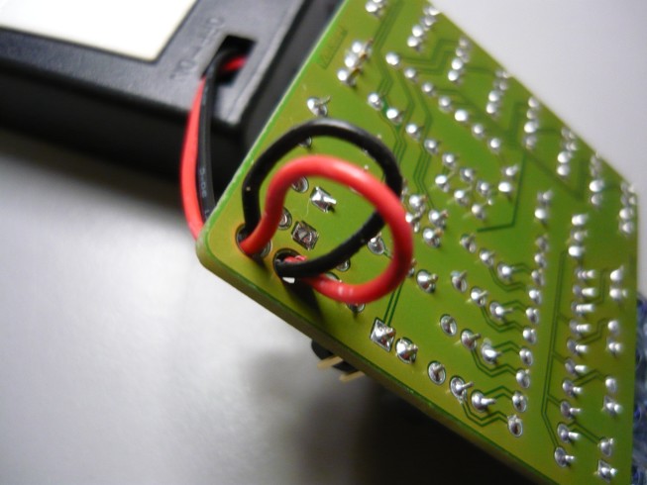
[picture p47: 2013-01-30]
doc/image/pwr-step03.jpg

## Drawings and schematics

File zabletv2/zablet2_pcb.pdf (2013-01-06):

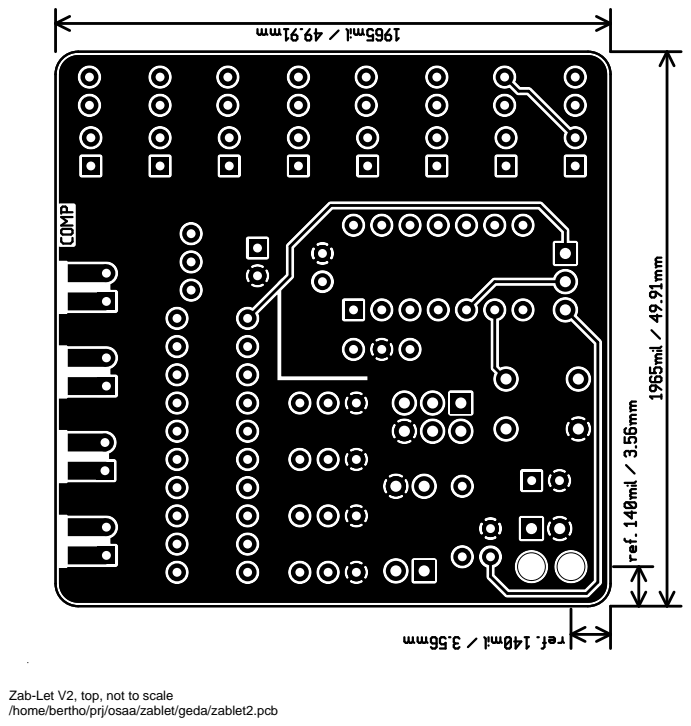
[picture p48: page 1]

Zab-Let V2, top, not to scale
/home/bertho/prj/osaa/zablet/geda/zablet2.pcb

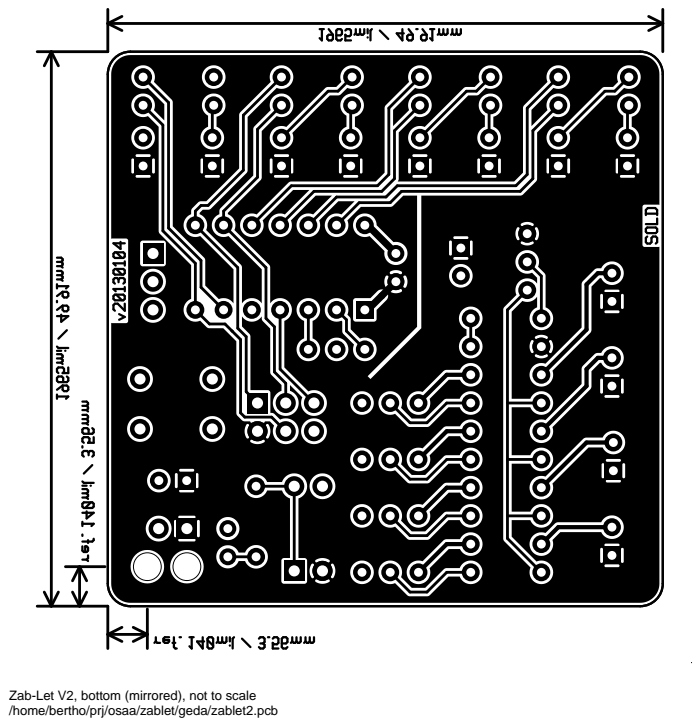
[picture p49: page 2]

Zab-Let V2, bottom (mirrored), not to scale

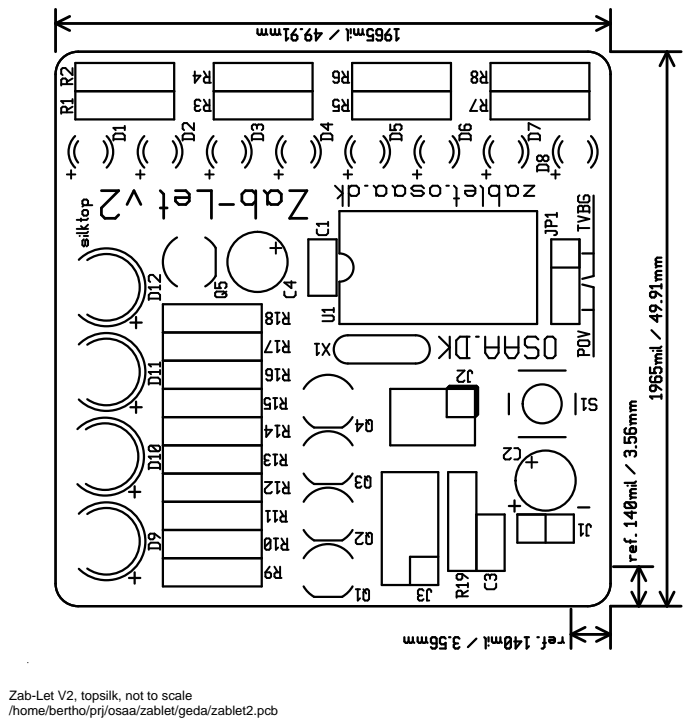
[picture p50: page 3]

Zab-Let V2, topsilk, not to scale

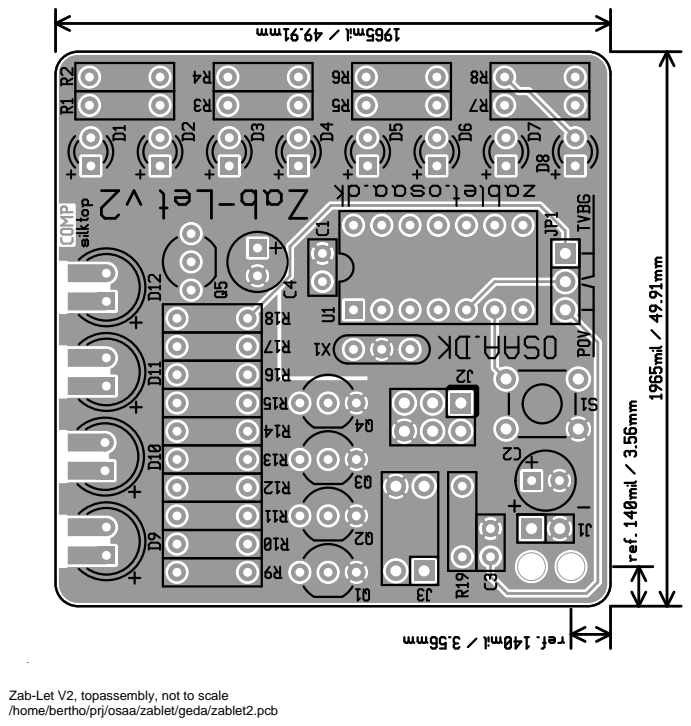
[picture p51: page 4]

Zab-Let V2, topassembly, not to scale

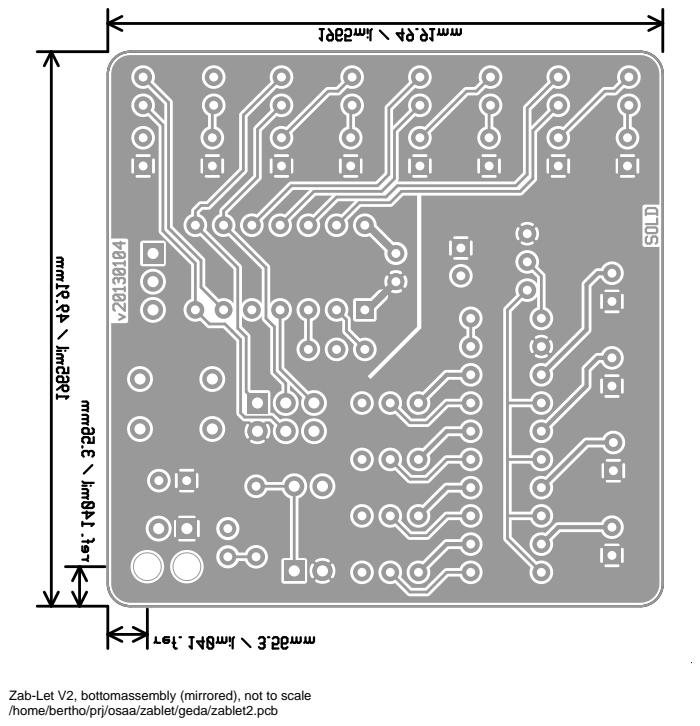
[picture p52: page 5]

Zab-Let V2, bottomassembly (mirrored), not to scale

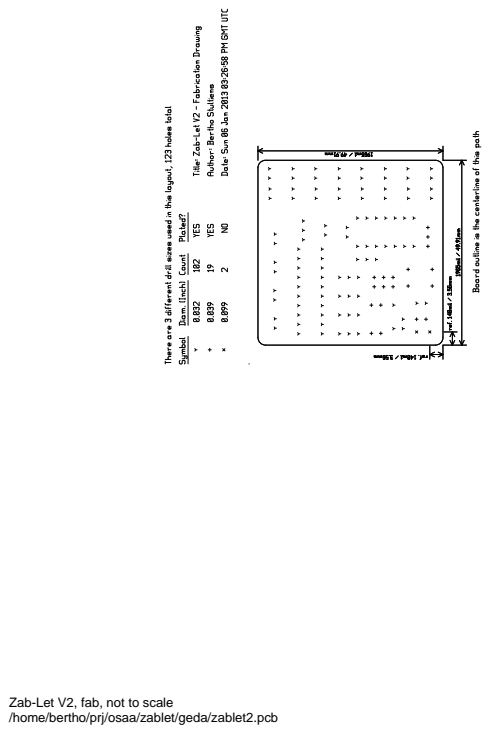
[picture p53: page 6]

Zab-Let V2, fab, not to scale

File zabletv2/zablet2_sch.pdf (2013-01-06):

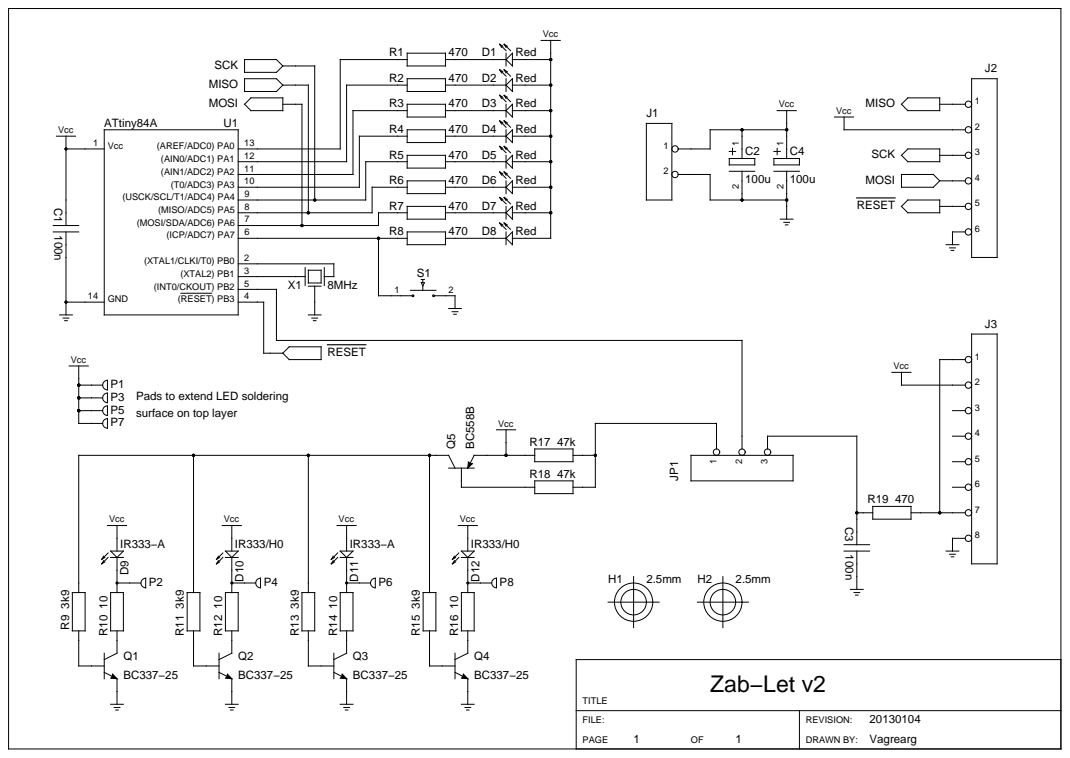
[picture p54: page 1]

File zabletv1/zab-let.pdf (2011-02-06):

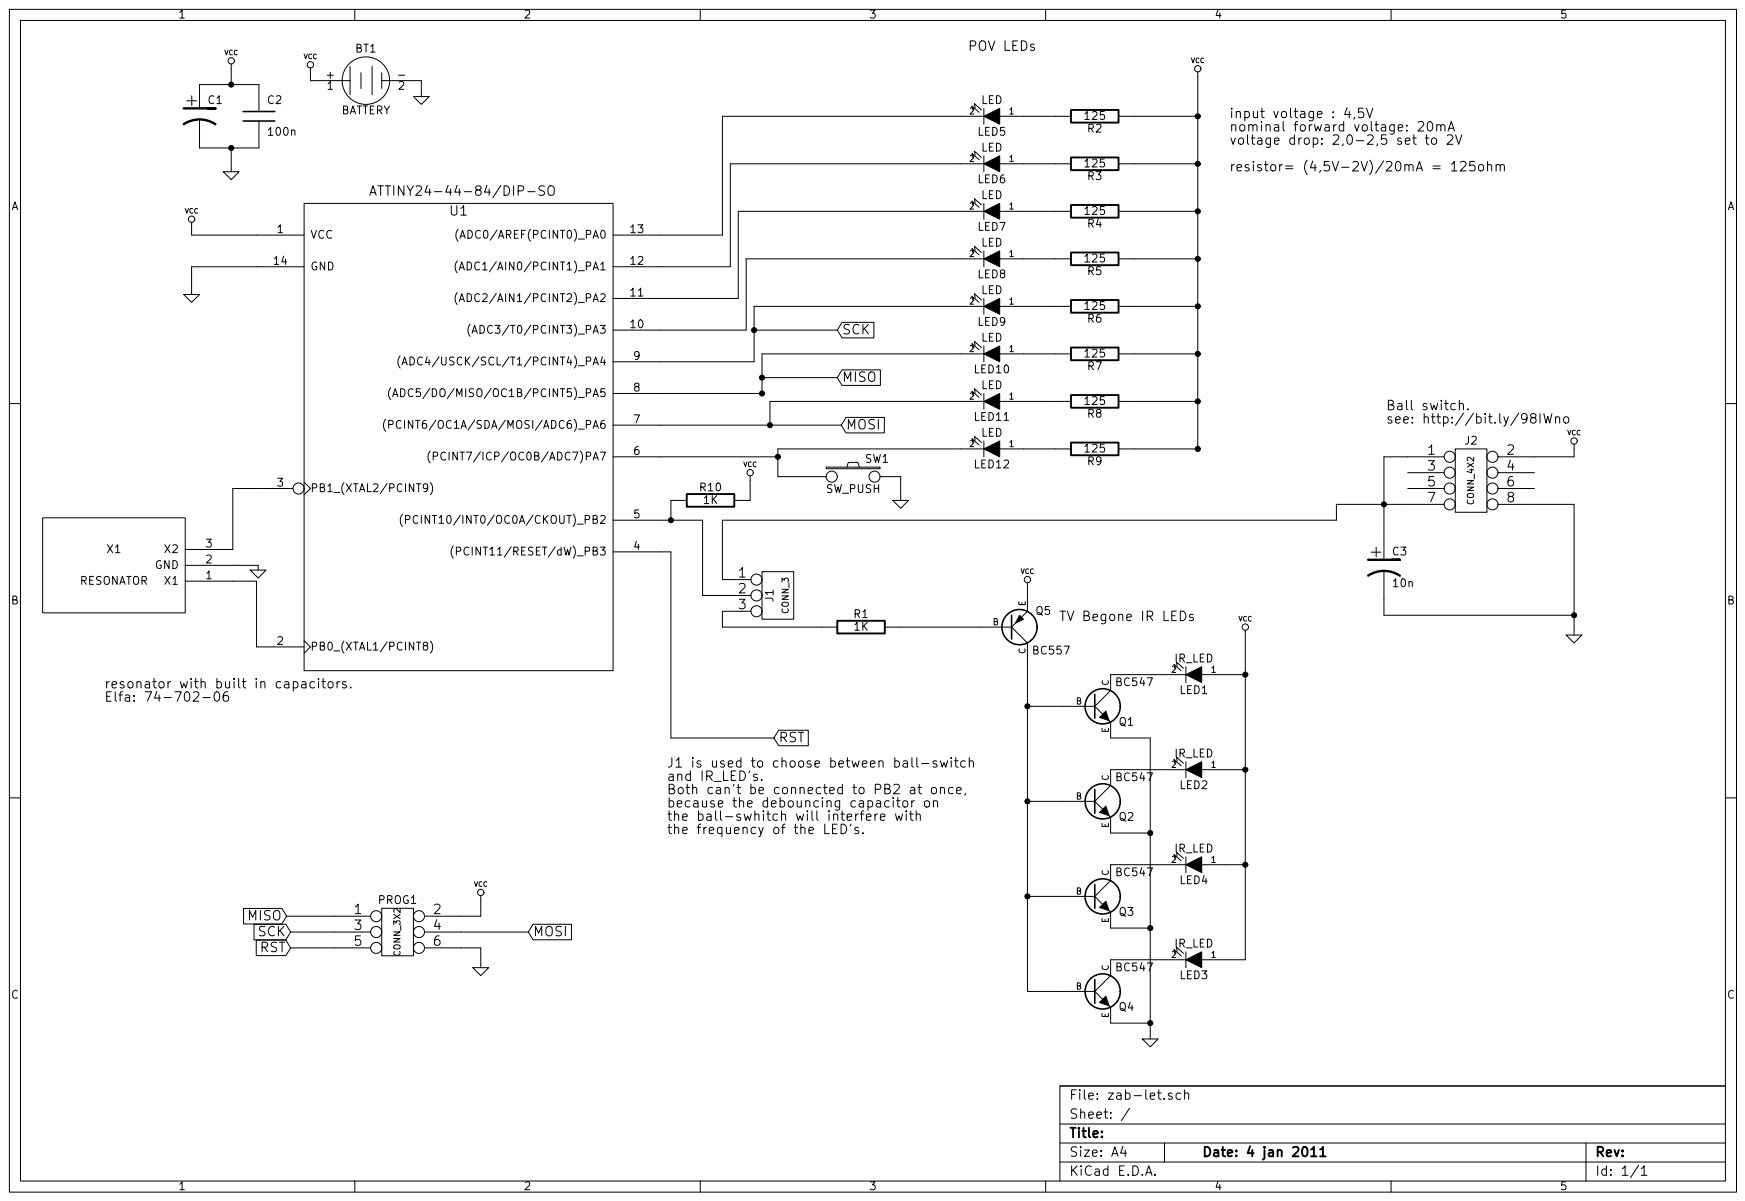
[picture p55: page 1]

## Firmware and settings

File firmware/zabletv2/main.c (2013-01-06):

/*
TV-B-Gone Firmware version 1.2
for use with ATtiny85v and v1.2 hardware
(c) Mitch Altman + Limor Fried 2009
Last edits, August 16 2009

With some code from:
Kevin Timmerman & Damien Good 7-Dec-07

Distributed under Creative Commons 2.5 -- Attib & Share Alike

This is the 'universal' code designed for v1.2 - it will select EU or NA
depending on a pulldown resistor on pin B1 !
*/

#include <limits.h>
#include <avr/io.h>             // this contains all the IO port definitions
#include <avr/eeprom.h>
#include <avr/sleep.h>          // definitions for power-down modes
#include <avr/pgmspace.h>       // definitions or keeping constants in program memory
#include <avr/wdt.h>
#include <avr/interrupt.h>

#include "main.h"
#include "util.h"

#define irled_on()	do { PORTB &= ~_BV(IRLED); } while(0)
#define irled_off()	do { PORTB |= _BV(IRLED); } while(0)
#define flash_on()	do { DDRA |= _BV(FLASHLED); } while(0)
#define flash_off()	do { DDRA &= ~_BV(FLASHLED); } while(0)
#define brownout_on()	do { DDRA |= _BV(BOLED); } while(0)
#define brownout_off()	do { DDRA &= ~_BV(BOLED); } while(0)

#define mode_tvbg()	do { irled_off(); DDRB |= _BV(IRLED); } while(0)
#define mode_pov()	do { irled_on(); DDRB &= ~_BV(IRLED); } while(0)

#define OCR_CTC		(F_CPU/64/100-1)		/* CTC mode ~100Hz */
#define start_timer1()	do { \
				OCR1AH = ((OCR_CTC >> 8) & 0xff); \
				OCR1AL = ((OCR_CTC) & 0xff); \
				TCCR1A = 0; \
				TCCR1B = _BV(WGM12) | _BV(CS11) | _BV(CS10);	/* Prescale /64 */ \
				TIMSK1 = _BV(OCIE1A);				/* Interrupt on OCR1A match */ \
			} while(0)
#define stop_timer1()	do { \
				TIMSK1 = 0; \
				TCCR1A = 0; \
				TCCR1B = 0; \
				OCR1AH = 0; \
				OCR1AL = 0; \
			} while(0)

#define F_BUTTON	0x01
#define F_POV		0x02

#define BUTTON_ONTIME		(INT8_MAX-1)	// If we hold the button 1.26 seconds, drop out of TVBG
#define BUTTON_OFFTIME		(-3)		// And come out when released
#define BUTTON_BLINKTIME	50


#ifndef ALL_CODES
uint8_t region = EU;		// by default our code is EU
#endif

volatile uint8_t wuflags;	// Wakeup flags to indicate POV switch or button
volatile int8_t button;		// Button indication


/*
 * This project transmits a bunch of TV POWER codes, one right after the other,
 * with a pause in between each.  (To have a visible indication that it is
 * transmitting, it also pulses a visible LED once each time a POWER code is
 * transmitted.)  That is all TV-B-Gone does.  The tricky part of TV-B-Gone was
 * collecting all of the POWER codes, and getting rid of the duplicates and
 * near-duplicates (because if there is a duplicate, then one POWER code will
 * turn a TV off, and the duplicate will turn it on again (which we certainly
 * do not want).  I have compiled the most popular codes with the duplicates
 * eliminated, both for North America (which is the same as Asia, as far as
 * POWER codes are concerned -- even though much of Asia USES PAL video) and
 * for Europe (which works for Australia, New Zealand, the Middle East, and
 * other parts of the world that use PAL video).
 *
 * Before creating a TV-B-Gone Kit, I originally started this project by
 * hacking the MiniPOV kit.  This presents a limitation, based on the size of
 * the Atmel ATtiny2313 internal flash memory, which is 2KB.  With 2KB we can
 * only fit about 7 POWER codes into the firmware's database of POWER codes.
 * However, the more codes the better! Which is why we chose the ATtiny85 for
 * the TV-B-Gone Kit.
 *
 * This version of the firmware has the most popular 100+ POWER codes for North
 * America and 100+ POWER codes for Europe. You can select which region to use
 * by soldering a 10K pulldown resistor.
 */


/*
This project is a good example of how to use the AVR chip timers.
*/


/*
The hardware for this project is very simple:
     ATtiny85 has 8 pins:
       pin 1   RST + Button
       pin 2   one pin of ceramic resonator MUST be 8.0 mhz
       pin 3   other pin of ceramic resonator
       pin 4   ground
       pin 5   OC1A - IR emitters, through a '2907 PNP driver that connects
               to 4 (or more!) PN2222A drivers, with 1000 ohm base resistor
               and also connects to programming circuitry
       pin 6   Region selector. Float for US, 10K pulldown for EU,
               also connects to programming circuitry
       pin 7   PB0 - visible LED, and also connects to programming circuitry
       pin 8   +3-5v DC (such as 2-4 AA batteries!)
    See the schematic for more details.

    This firmware requires using an 8.0MHz ceramic resonator
       (since the internal oscillator may not be accurate enough).

    IMPORTANT:  to use the ceramic resonator, you must perform the following:
                    make burn-fuse_cr
*/



// This function delays the specified number of 10 microseconds it is
// 'hardcoded' and is calibrated by adjusting DELAY_CNT in main.h Unless you
// are changing the crystal from 8mhz, dont mess with this.
void delay_ten_us(uint16_t us)
{
	uint8_t timer;
	while (us != 0) {
		// for 8MHz we want to delay 80 cycles per 10 microseconds
		// this code is tweaked to give about that amount.
		for (timer=0; timer <= DELAY_CNT; timer++) {
			NOP;
			NOP;
		}
		NOP;
		us--;
	}
}


void powerDown(void)
{
	// Shut down everything and put the CPU to sleep
	TCCR0A = 0;			// turn off frequency generator (should be off already)
	TCCR0B = 0;			// turn off frequency generator (should be off already)
	mode_pov();
	flash_off();
	stop_timer1();
	PORTA = 0xff;			// Turn on all pull-ups to prevent indeterminate input states

	wdt_disable();			// turn off the watchdog (since we want to sleep
	delay_ten_us(1000);		// wait 10 millisec

	MCUCR = _BV(SM1) | _BV(SE);	// power down mode,  SE enables Sleep Modes
	sleep_cpu();			// put CPU into Power Down Sleep Mode
	delay_ten_us(10);		// Let any interrupts be processed
	PORTA = _BV(BUTTONPIN);		// Turn off all pull-ups except input button
	start_timer1();
}


/*
 * This function is the 'workhorse' of transmitting IR codes. Given the on and
 * off times, it turns on the PWM output on and off to generate one 'pair' from
 * a long code. Each code has ~50 pairs!
 */
void xmitCodeElement(uint16_t ontime, uint16_t offtime, uint8_t PWM_code )
{
	// start Timer0 outputting the carrier frequency to IR emitters on and OC0A
	// (PB2, pin 5)
	TCNT0 = 0; // reset the timers so they are aligned
	TIFR0 = 0;  // clean out the timer flags

	if(PWM_code) {
		// 99% of codes are PWM codes, they are pulses of a carrier
		// frequecy Usually the carrier is around 38KHz, and we
		// generate that with PWM timer 0
		TCCR0A =_BV(COM0A0) | _BV(WGM01);          // set up timer 0
		TCCR0B = _BV(CS00);
	} else {
		// However some codes dont use PWM in which case we just turn
		// the IR LED on for the period of time.
		irled_on();
	}

	// Now we wait, allowing the PWM hardware to pulse out the carrier
	// frequency for the specified 'on' time
	delay_ten_us(ontime);

	// Now we have to turn it off so disable the PWM output
	TCCR0A = 0;
	TCCR0B = 0;
	// And make sure that the IR LED is off too (since the PWM may have
	// been stopped while the LED is on!)
	irled_off();

	// Now we wait for the specified 'off' time
	delay_ten_us(offtime);
}

/*
 * This is kind of a strange but very useful helper function Because we are
 * using compression, we index to the timer table not with a full 8-bit byte
 * (which is wasteful) but 2 or 3 bits. Once code_ptr is set up to point to
 * the right part of memory, this function will let us read 'count' bits at a
 * time which it does by reading a byte into 'bits_r' and then buffering it.
 */

uint8_t bitsleft_r;	/* = 0;*/ // By def. it is init to zero
uint8_t bits_r;		/* = 0;*/
PGM_P code_ptr;

// we cant read more than 8 bits at a time so dont try!
uint8_t read_bits(uint8_t count)
{
	uint8_t i;
	uint8_t tmp = 0;

	// we need to read back count bytes
	for(i = 0; i < count; i++) {
		// check if the 8-bit buffer we have has run out
		if(bitsleft_r == 0) {
			// in which case we read a new byte in
			bits_r = pgm_read_byte(code_ptr++);
			// and reset the buffer size (8 bites in a byte)
			bitsleft_r = 8;
		}
		// remove one bit
		bitsleft_r--;
		// and shift it off of the end of 'bits_r'
		tmp |= (((bits_r >> (bitsleft_r)) & 1) << (count-1-i));
	}
	// return the selected bits in the LSB part of tmp
	return tmp;
}


/*
 * The C compiler creates code that will transfer all constants into RAM when
 * the microcontroller resets. Since this firmware has a table (powerCodes)
 * that is too large to transfer into RAM, the C compiler needs to be told to
 * keep it in program memory space. This is accomplished by the macro PROGMEM
 * (this is used in the definition for powerCodes). Since the C compiler
 * assumes that constants are in RAM, rather than in program memory, when
 * accessing powerCodes, we need to use the pgm_read_word() and pgm_read_byte
 * macros, and we need to use powerCodes as an address. This is done with
 * PGM_P, defined below.
 * For example, when we start a new powerCode, we first point to it with the
 * following statement:
 *	PGM_P thecode_p = pgm_read_word(powerCodes+i);
 * The next read from the powerCode is a byte that indicates the carrier
 * frequency, read as follows:
 *	const uint8_t freq = pgm_read_byte(code_ptr++);
 * After that is a byte that tells us how many 'onTime/offTime' pairs we have:
 *	const uint8_t numpairs = pgm_read_byte(code_ptr++);
 * The next byte tells us the compression method. Since we are going to use a
 * timing table to keep track of how to pulse the LED, and the tables are
 * pretty short (usually only 4-8 entries), we can index into the table with
 * only 2 to 4 bits. Once we know the bit-packing-size we can decode the pairs
 *	const uint8_t bitcompression = pgm_read_byte(code_ptr++);
 * Subsequent reads from the powerCode are n bits (same as the packing size)
 * that index into another table in ROM that actually stores the on/off times
 *	const PGM_P time_ptr = (PGM_P)pgm_read_word(code_ptr);
 */

ISR(PCINT0_vect)
{
	wuflags |= F_BUTTON;
}

ISR(PCINT1_vect)
{
	wuflags |= F_POV;
}

ISR(TIM1_COMPA_vect)
{
	uint8_t p, d, b;
	p = PORTA;
	d = DDRA;
	PORTA |= _BV(BUTTONPIN);
	DDRA &= ~_BV(BUTTONPIN);
	b = PINA & _BV(BUTTONPIN);
	PORTA = p;
	DDRA = d;

	/*
	 * Count button up when pressed
	 * Count button down when released
	 * Set to 0 on change
	 */
	if(button >= 0 && !b) {
		if(button < INT8_MAX)
			button++;
	} else if(button <= 0 && b) {
		if(button > INT8_MIN)
			button--;
	} else
		button = 0;
}

#define PROGRESS_BITS 8


void turnOffTVs(void)
{
#ifndef ALL_CODES
	uint8_t i;
	uint8_t numCodes = region == US ? pgm_read_byte(&num_NAcodes) : pgm_read_byte(&num_EUcodes);
	// Indicate how big our database is
	DEBUGP(putstring("\n\rNA Codesize: "); putnum_ud(pgm_read_byte(&num_NAcodes)););
	DEBUGP(putstring("\n\rEU Codesize: "); putnum_ud(pgm_read_byte(&num_EUcodes)););
#else
	uint16_t i;
	uint16_t numCodes = pgm_read_word(&num_Allcodes);
#endif
	mode_tvbg();	// Set the IRLED pin to output
	PORTA = 0x00;	// And disable pull-up the switch input

	// Starting execution loop
	delay_ten_us(25000);

	// We may have different number of codes in either database

	// for every POWER code in our collection
	for(i = 0 ; i < numCodes; i++) {
		// print out the code # we are about to transmit
		DEBUGP(putstring("\n\r\n\rCode #: "); putnum_ud(i));

		// If we hold the button x seconds, drop out
		if(button >= BUTTON_ONTIME) {
			button = 0;
			DDRA = 0xaa;
			while(button >= BUTTON_OFFTIME) {
				if(button >= BUTTON_BLINKTIME) {
					button = 0;
					DDRA ^= 0xff;
				}
			}
			break;
		}

		/*
		 * Output some indication of progress on the POV leds while
		 * sending zap codes.
		 */
#ifndef ALL_CODES
		uint8_t pbit = i / (numCodes/PROGRESS_BITS);
#else
		uint8_t pbit = i * PROGRESS_BITS / numCodes;
#endif
		uint8_t leds = ((1 << pbit)-1);
		if(button <= -(BUTTON_BLINKTIME)) {
			button = 0;
			leds |= 1 << pbit;
		}
		DDRA = leds;

		// Flush previous bits, so that next code starts with a fresh
		// set of 8 bits.
		bitsleft_r = 0;

		// To keep Watchdog from resetting in middle of code.
		wdt_reset();

		// point to next POWER code, from the right database
#ifdef ALL_CODES
		code_ptr = (PGM_P)pgm_read_word(AllpowerCodes+i);
#else
		if (region == US) {
			code_ptr = (PGM_P)pgm_read_word(NApowerCodes+i);
		} else {
			code_ptr = (PGM_P)pgm_read_word(EUpowerCodes+i);
		}
#endif

		// Read the carrier frequency from the first byte of code structure
		// set OCR for Timer1 to output this POWER code's carrier frequency
		const uint8_t freq = pgm_read_byte(code_ptr++);
		OCR0A = freq;

		// Print out the frequency of the carrier and the PWM settings
		DEBUGP(putstring("\n\rOCR1: "); putnum_ud(freq););
		DEBUGP(uint16_t x = (freq+1) * 2; putstring("\n\rFreq: "); putnum_ud(F_CPU/x););

		// Get the number of pairs, the second byte from the code struct
		const uint8_t numpairs = pgm_read_byte(code_ptr++);
		DEBUGP(putstring("\n\rOn/off pairs: "); putnum_ud(numpairs));

		// Get the number of bits we use to index into the timer table
		// This is the third byte of the structure
		const uint8_t bitcompression = pgm_read_byte(code_ptr++);
		DEBUGP(putstring("\n\rCompression: "); putnum_ud(bitcompression));

		// Get pointer (address in memory) to pulse-times table
		// The address is 16-bits (2 byte, 1 word)
		const PGM_P time_ptr = (PGM_P)pgm_read_word(code_ptr);
		code_ptr += 2;

		// Transmit all codeElements for this POWER code
		// (a codeElement is an onTime and an offTime)
		// transmitting onTime means pulsing the IR emitters at the carrier
		// frequency for the length of time specified in onTime
		// transmitting offTime means no output from the IR emitters for the
		// length of time specified in offTime

		/*
		// print out all of the pulse pairs
		for (uint8_t k=0; k<numpairs; k++) {
			uint8_t ti;
			ti = (read_bits(bitcompression)) * 4;
			// read the onTime and offTime from the program memory
			ontime = pgm_read_word(time_ptr+ti);
			offtime = pgm_read_word(time_ptr+ti+2);
			DEBUGP(putstring("\n\rti = "); putnum_ud(ti>>2); putstring("\tPair = "); putnum_ud(ontime));
			DEBUGP(putstring("\t"); putnum_ud(offtime));
		}
		*/

		// For EACH pair in this code....
		for(uint8_t k = 0; k < numpairs; k++) {
			// Read the next 'n' bits as indicated by the compression variable
			// The multiply by 4 because there are 2 timing numbers per pair
			// and each timing number is one word long, so 4 bytes total!
			uint8_t ti = (read_bits(bitcompression)) * 4;

			// read the onTime and offTime from the program memory
			uint16_t ontime = pgm_read_word(time_ptr+ti);		// read word 1 - ontime
			uint16_t offtime = pgm_read_word(time_ptr+ti+2);	// read word 2 - offtime

			// transmit this codeElement (ontime and offtime)
			xmitCodeElement(ontime, offtime, (freq!=0));
		}

		// delay before transmitting next POWER code
		delay_ten_us(5000);
	}

	mode_pov();

	DDRA = 0x00;		// Turn off POV leds
	PORTA = _BV(BUTTONPIN);	// And pull-up the switch input

	// flash the visible LED on PB0  4 times to indicate that we're done
	delay_ten_us(-1);	// wait maxtime
	for(i = 0; i < 4; i++) {
		wdt_reset();
		flash_on();
		delay_ten_us(3000);	// 30 millisec delay
		flash_off();
		if(i == 3)
			break;
		delay_ten_us(15000);	// 150 millisec delay
	}
}

void povShow(uint8_t dir)
{
	uint16_t pre_delay;
	uint16_t int_delay;
	uint16_t nelem;

#ifdef USE_EEPROM
	pre_delay = eeprom_read_word(&pov_data.pre_delay);
	int_delay = eeprom_read_word(&pov_data.int_delay);
	nelem = eeprom_read_word(&pov_data.nelem);
#else
	pre_delay = pgm_read_word(&pov_data.pre_delay);
	int_delay = pgm_read_word(&pov_data.int_delay);
	nelem = pgm_read_word(&pov_data.nelem);
#endif
	PORTA = 0;
	DDRA = 0;

	wdt_reset();			// All should be done in 0.5s, so the dog should keep quiet
	delay_ten_us(pre_delay);	// Wait for the movement to pick up
	wuflags = 0;			// Next detection may be earlier than expected; setup detection
	wdt_reset();
	if(dir) {
		for(int16_t i = 0; i < nelem; i++) {
#ifdef USE_EEPROM
			DDRA = ~eeprom_read_byte(&pov_data.data[i]);	// Set the port data from eeprom
#else
			DDRA = ~pgm_read_byte(&pov_data.data[i]);	// Set the port data from eeprom
#endif
			delay_ten_us(int_delay);
		}
	} else {
		for(int16_t i = nelem-1; i >= 0; i--) {
#ifdef USE_EEPROM
			DDRA = ~eeprom_read_byte(&pov_data.data[i]);	// Set the port data from eeprom
#else
			DDRA = ~pgm_read_byte(&pov_data.data[i]);	// Set the port data from eeprom
#endif
			delay_ten_us(int_delay);
		}
	}
	DDRA = 0;
	PORTA = _BV(BUTTONPIN);
}

int main(void)
{
	DDRA  = 0x00;		// Port A to input (POV LEDs off)
	PORTA = _BV(BUTTONPIN);	// Leds off with pull-up on PA7 (switch)

	DDRB  = 0x00;		// Input on the combined POV input/TVBG IR LED output
	PORTB = 0x00;		// Disable pull-up. The pin is externally pulled up for TVBG

	TCCR0A = 0;		// Turn off PWM/freq gen, should be off already
	TCCR0B = 0;		// Turn off PWM/freq gen, should be off already

	start_timer1();

	uint8_t i = MCUSR;		// Save reset reason
	MCUSR = 0;			// clear watchdog flag
	WDTCSR = _BV(WDCE) | _BV(WDE);	// enable WDT disable
	WDTCSR = 0;			// disable WDT while we setup

	DEBUGP(putstring_nl("Hello!"));

	PCMSK0 = _BV(PCINT7);		// Enable pin change int on PA7
	PCMSK1 = _BV(PCINT10);		// Enable pinc change int on PB2
	GIMSK |= _BV(PCIE0) | _BV(PCIE1);
	sei();

	// check the reset flags
	if(i & _BV(BORF)) {
		// Brownout detected
		DEBUGP(putstring_nl("Battery low!"));

		// Flash out an error and go to sleep
		wdt_reset();
		brownout_on();
		delay_ten_us(50);
		brownout_off();
		delay_ten_us(50000);
		brownout_on();
		delay_ten_us(50);
		brownout_off();
		powerDown();
	}

	delay_ten_us(5000);		// Let everything settle for a bit

	while (1) {
		powerDown();		// Wait for the user to hit the button.
		wdt_enable(WDTO_8S);
		button = 0;

		if(wuflags & F_POV) {
			// wakeup flags are cleared delayed in the show
			povShow(PINB & _BV(IRLED));
		} else if(wuflags & F_BUTTON) {
			turnOffTVs();	// The button woke us, turn off those damn TVs
			wuflags = 0;
		}
	}
}

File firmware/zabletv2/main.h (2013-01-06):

#ifndef __TVBG_MAIN_H
#define __TVBG_MAIN_H

// What pins do what
#define FLASHLED	PA0
#define BOLED		PA1
#define IRLED		PB2
#define BUTTONPIN	PA7

// Two regions!
#define US 1
#define EU 0

// Lets us calculate the size of the NA/EU databases
#define NUM_ELEM(x) (sizeof (x) / sizeof (*(x)))

// set define to 0 to turn off debug output
#define DEBUG 0
#define DEBUGP(x) if (DEBUG == 1) { x ; }


// Shortcut to insert single, non-optimized-out nop
#define NOP __asm__ __volatile__ ("nop")

// Tweak this if neccessary to change timing
#define DELAY_CNT 11

// Makes the codes more readable. the OCRA is actually programmed in terms of
// 'periods' not 'freqs' - that is, the inverse!
#define freq_to_timerval(x) ((F_CPU / x - 1)/ 2)

#define PULSE_CODE 0

// The structure of compressed code entries
struct IrCode {
  uint8_t timer_val;
  uint8_t numpairs;
  uint8_t bitcompression;
  uint16_t const *times;
  uint8_t codes[];
};

#ifdef ALL_CODES
extern const struct IrCode * const AllpowerCodes[];
extern const uint16_t num_Allcodes;
#endif
#ifdef NA_CODES
extern const struct IrCode * const NApowerCodes[];
extern const uint8_t num_NAcodes;
#endif
#ifdef EU_CODES
extern const struct IrCode * const EUpowerCodes[];
extern const uint8_t num_EUcodes;
#endif

struct eeprom_data_t {
	uint16_t	pre_delay;	// Delay from switch detect before starting show
	uint16_t	int_delay;	// Inter-pixel delay
	uint16_t	nelem;		// Number of elements of data
	uint8_t		data[];
};

#ifdef USE_EEPROM
extern const struct eeprom_data_t pov_data;
#else
extern const struct eeprom_data_t pov_data;
#endif

#endif

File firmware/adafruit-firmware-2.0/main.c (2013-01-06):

/*
TV-B-Gone Firmware version 2.0
for use with ATtiny85v and v2.0 hardware (see below)

**********  Version History  **********

v1.2	(c) Mitch Altman + Limor Fried 2009
	Last edits, August 16 2009
	With some code from Kevin Timmerman & Damien Good 7-Dec-07

v2.0	(c) PorkRhombus December 2012			**** This is a universal version with most of the US and EU codes ****

	Added modes and made a minor hardware change to support this. The switch to GND now connects to pin 6 (PB1) so there
	is no region select resistor. For EU operation, power up the device with the button pressed and immediately release.
	The debugging outputs have been removed from this version. Note that in v2.0 the pushbutton does not reset the
	device, it simply wakes it from sleep by means of a pin change interrupt. The mode and region settings are maintained
	until power is disconnected or low battery voltage causes a brownout reset. If using a rechargeable battery and
	charging through the ICP header, settings can be maintained indefinitely.

	Modes are as follows:

	Mode 1:	Default mode. Pressing the button causes all codes to be transmitted just like before.
		However the LED is now solid ON because the blinking draws too much unwanted attention.
		Also, the pause between codes has been reduced to 75ms. There are no region blinks or end-of-run blinks
		as I didn't find these remotely useful, nor indeed could I tell the difference between 3 and 4 rapid blinks.

	Mode 2: Codes are transmitted as long as the button is held down.
		Each time it is pressed, transmission restarts from code #1.

	Mode 3: Codes are transmitted one at a time. Each code is accompanied by a flash (double flash every multiple of 10).
		In this way one can determine which code is switching off a particular TV and the WORLDcodes.c file can then
		be edited, and the program recompiled, to change the transmission sequence.

	After power-up, the LED flashes for 2 seconds during which time any further press will cause the device to enter mode
	selection. Subsequent presses at this time cause the modes to be cycled through. To enter your selection, wait a few
	seconds after the last button press.

	Technical notes can be found a little lower down.


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
		<<<<<<<<<<<<<<  Distributed under Creative Commons 2.5 -- Attribution & Share Alike >>>>>>>>>>>>>>>

That means that if you re-distribute all or part of this code, you should (a) credit the original authors and (b) likewise share
any projects that you base on it (include a notice like the one above in your distribution). For more info go to: 

						www.creativecommons.org. Thank you.


FINALLY ......... please use the TV-b-Gone as a force for GOOD in the universe.
There's no glory in switching off TVs in places where people have gathered specifically to watch them.

******************************************
*CA9620455B9CDC1BBB04094FA206C462FCFD1C3F*
******************************************
*/

#include <avr/io.h>             // this contains all the IO port definitions
#include <avr/eeprom.h>
#include <avr/sleep.h>          // definitions for power-down modes
#include <avr/pgmspace.h>       // definitions for keeping constants in program memory
#include <avr/wdt.h>
#include <avr/interrupt.h>
#include "main.h"
#include "util.h"


/*
This project transmits a bunch of TV POWER codes, one right after the other, 
with a pause in between each.  (To have a visible indication that it is 
transmitting, it also pulses a visible LED once each time a POWER code is 
transmitted.)  That is all TV-B-Gone does.  The tricky part of TV-B-Gone 
was collecting all of the POWER codes, and getting rid of the duplicates and 
near-duplicates (because if there is a duplicate, then one POWER code will 
turn a TV off, and the duplicate will turn it on again (which we certainly 
do not want).  I have compiled the most popular codes with the 
duplicates eliminated, both for North America (which is the same as Asia, as 
far as POWER codes are concerned -- even though much of Asia USES PAL video) 
and for Europe (which works for Australia, New Zealand, the Middle East, and 
other parts of the world that use PAL video).

Before creating a TV-B-Gone Kit, I originally started this project by hacking 
the MiniPOV kit.  This presents a limitation, based on the size of
the Atmel ATtiny2313 internal flash memory, which is 2KB.  With 2KB we can only 
fit about 7 POWER codes into the firmware's database of POWER codes.  However,
the more codes the better! Which is why we chose the ATtiny85 for the 
TV-B-Gone Kit.

This version of the firmware has the most popular 100+ POWER codes for 
North America and 100+ POWER codes for Europe.
*/


/*
This project is a good example of how to use the AVR chip timers.
On the other hand, it sets a bad example by making extensive use of delays !!
*/


/*	T E C H N I C A L   N O T E S
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

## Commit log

2011-02-06 Initial copy from svn
    [zab-let.brd, zab-let.sch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]
2011-02-07 Last update from Subversion
    [zab-let.brd, zab-let.sch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]
2012-12-27 Add new version Zab-Let
    [elfa-bom.ods, zablet2.bom.ods, zablet2.sch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]
2013-01-06 PCB with LEDs moved from side
    [zablet2.bom.ods, zablet2.sch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]
2013-01-06 Add missing unplated drill file and rest of support+docs
2013-01-06 Explicitly name version 2
    [zablet2.bom.ods, zablet2.sch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]
2013-01-06 Reorganize version 1 into own subdir
    [elfa-bom.ods, zab-let.brd, zab-let.sch]
2013-01-06 move old (test) firmware to v1 subdir
    [zablet.obj]
2013-01-06 Production gerbers for Eurocircuits
2013-01-30 Add overview and battery connections steps images
